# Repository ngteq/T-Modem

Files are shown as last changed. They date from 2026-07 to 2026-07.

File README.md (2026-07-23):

# T-Modem > USB-5V|12-Volt Terminal-Modem Reference
**Non-Profit for the Radio-World and easy to deploy/repair is parted by AI-Services**<br>
<br><br>
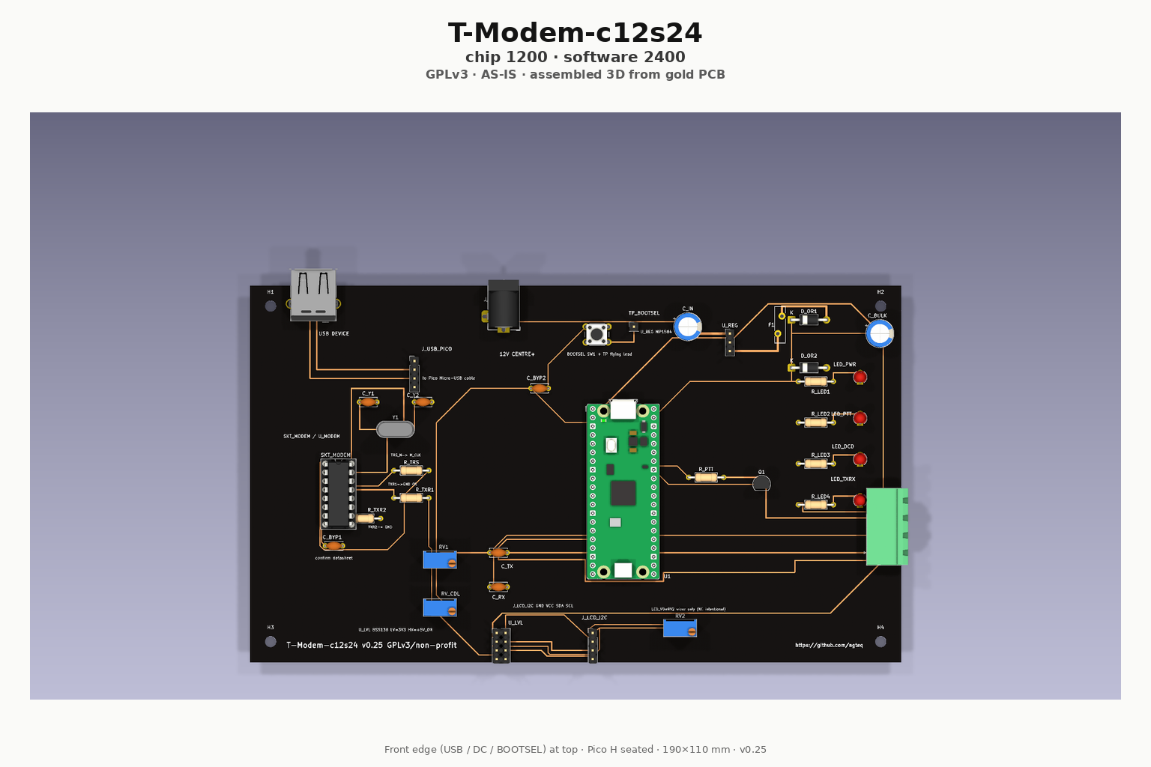
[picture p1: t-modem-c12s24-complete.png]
T-Modem-c12s24 complete assembled board (KiCad 3D, Pico seated)


<br>

> **No firmware / no host software yet** — trees under `firmware/` and `software/` are placeholders only.  
> **Build a working hardware prototype first** (rails, assembly, bench checks).
> KiCad PCB is for **learning-by-doing** and small-run fab — run **DRC** and fix reported issues before ordering boards.  

**T-Modem** = **Terminal-Modem** — a real packet-radio modem board (registers + firmware) for host stacks such as MAX25-Stack.

**PHY mark:** **T-Modem-c12s24** — **c12** = chip **1200** (TCM3105-class AFSK) · **s24** = software **2400** (Pico firmware DSP later). One board; **no** second 2400 modem IC.

**Version:** **0.25** — hardware-only standard reference (**baseline** while building toward **v1.0**; software after the build) · [docs/HARDWARE-BASELINE.md](docs/HARDWARE-BASELINE.md)  
**License:** [GNU GPLv3](LICENSE)  
**Project intent:** non-profit / non-commercial community hardware project under GPLv3 (no separate legal entity claimed here).

**AS-IS — no support, no warranty:** This project and all materials are provided **as-is**. There is **no support** and **no warranty** of any kind. GPLv3 already disclaims warranty; this is also **project policy**.

**Scope:** T-Modem is a **standard reference only**. Custom product lines, per-customer variants, or commercial SKUs beyond that reference are **not** T-Modem — they are separate projects.

**Status/State:** The **v0.25** hardware design is **not** being redesigned. Develop it **as-is** to **v1.0** by **building** the board; **firmware / software come after** that. Change HW only if the build proves a blocking error.

Product docs and repo practice follow the operator publication standard (KISS, technical-right only, GPLv3 non-profit). This repository holds the complete product (hardware, firmware, shipped docs).

**Git branch:** you are on **`c12s24`** (active product tree). GitHub **`main`** is an index only — see [BRANCHES.md](BRANCHES.md).

---

## v0.25 release (this tag)

| Ships | Does not ship |
|---|---|
| BOM with preferred commodity candidates + longevity notes | Firmware / host software |
| Fabricable netlist + KiCad project (190×110 mm TH PCB) | Fab-verified Gerbers without DRC pass |
| PCB outline + placement + assembly notes | Invented radio mic pinouts |
| Power · USB-A · green LCD · Pico UF2 · **TCM3105-class AFSK IF**
| **Hobby-friendly soldering** (sockets + through-hole) | Reflow / fine-pitch SMD as the default path |

See [docs/RELEASE-v0.25.md](docs/RELEASE-v0.25.md) · [docs/v0.25-VERIFICATION.md](docs/v0.25-VERIFICATION.md) · [docs/BOM.md](docs/BOM.md) · [docs/SCHEMATIC.md](docs/SCHEMATIC.md) · [docs/PCB-ASSEMBLY.md](docs/PCB-ASSEMBLY.md) · [hardware/](hardware/).

**Firmware / software:** placeholders only — [firmware/README.md](firmware/README.md) · [software/README.md](software/README.md).

---

## Hobby-friendly soldering

v0.25 is aimed at **hand soldering for anyone who can solder reasonably well** — not only professional reflow lines. Goal: **best value for money**, socketed, replaceable parts.

| Practice | Intent |
|---|---|
| **DIP / module sockets** | Modem IC in a **16-pin DIP socket**; Pico and LCD on **2.54 mm female sockets** |
| **Through-hole first** | Resistors, diodes, LEDs, trimmers, USB-A, barrel jack, screw terminals — **TH** (cheap commodity packs) |
| **Pre-made cheap modules** | Pico (~few €), green 16×2 LCD module, MP1584-class buck module — plug in, no fine-pitch MCU soldering |
| **I²C LCD level shift** | 5 V LCD1602 I²C backpack ↔ Pico 3.3 V: BSS138-class 4-ch module (**LV=3.3 V** · **HV=5 V** · GND common) — see [docs/BOM.md](docs/BOM.md) `U_LVL` |
| **Not required** | Stencil reflow, QFN/BGA, expensive milled sockets, or SOIC as the only modem package |

Assembly and cheap-part notes: [docs/PCB-ASSEMBLY.md](docs/PCB-ASSEMBLY.md) · [docs/BOM.md](docs/BOM.md) · [docs/ORDERING-BUDGET.md](docs/ORDERING-BUDGET.md).

---

## Role

| This repo | Elsewhere |
|---|---|
| Complete T-Modem **standard reference**: hardware, (future) firmware, BOM/PCB, shipped docs | MAX25-Stack: **thin plugin only** later (discover / talk; host keeps AX.25 / KISS) |
| Board owns modem PHY + register file + thin KISS bridge (when FW exists)

**Settled scope**

| Item | Fact |
|---|---|
| Form | Rectangle **190 × 110 mm** (v0.25 outline; §0.26 larger OK) |
| Modulation | AFSK **1200** (TCM3105-class) + **2400** (MCU DSP, FW later) |
| Host link | USB 2.0 **Type A receptacle** (toward PC); no active hub required |
| Power | **USB-only OK**; barrel **12 V** + buck **optional** (on reference); USB OR; optional active hub / **5 V** into USB/OR rail |
| Display | HD44780-class **16×2** character LCD, **green backlight** (preferred) |
| MCU | **Raspberry Pi Pico** (RP2040), preferably **Pico H** on socketed headers — ROM **UF2** field flash |
| Modem IC | **TCM3105**-class Bell-202 in **DIP + socket**
| Assembly | **Hobby-friendly:** sockets + through-hole; see section above |
| Field flash | Via the **USB Type-A** port to the PC (when FW exists) |
| Layer split | Host owns AX.25; board = modem + thin KISS |
| Radio equipment | Screw-terminal AF/PTT labels only — **no** invented mic pinouts |

---

## Build

| Step | v0.25 status |
|---|---|
| Schematic / netlist | **Documented** — [docs/SCHEMATIC.md](docs/SCHEMATIC.md) |
| KiCad project | **Present** — [hardware/kicad/t-modem/](hardware/kicad/t-modem/) (KiCad ≥8; docs images via `scripts/render_docs_images.py`) |
| PCB outline / placement | **Documented** — [docs/PCB-ASSEMBLY.md](docs/PCB-ASSEMBLY.md) · [docs/PCB-LAYOUT.md](docs/PCB-LAYOUT.md) |
| BOM | **Candidates** — [docs/BOM.md](docs/BOM.md) · [hardware/bom/BOM.csv](hardware/bom/BOM.csv) |
| Verification | [docs/v0.25-VERIFICATION.md](docs/v0.25-VERIFICATION.md) |
| Firmware tree | **Placeholder only** |
| Fab | **DRC clean** → export Gerbers — see [hardware/fab/README.md](hardware/fab/README.md). Personal small-run OK — **AS-IS** |

---

## Operate

| Topic | Status |
|---|---|
| Host attach (USB CDC/ACM) | **TBD** until firmware |
| Register map / KISS | **TBD** — see [docs/OVERVIEW.md](docs/OVERVIEW.md) |
| Radio cable / pinout per model | **TBD** — expand from verified notes only |
| RX before live TX | Operator practice when RF path exists |

Site-private secrets belong in `./local/` (gitignored) — never commit passwords or host inventories.

---

## Documentation

| Doc | Content |
|-----|---|
| [docs/README.md](docs/README.md) | Doc index |
| [docs/RELEASE-v0.25.md](docs/RELEASE-v0.25.md) | v0.25 hardware-only release note |
| [docs/v0.25-VERIFICATION.md](docs/v0.25-VERIFICATION.md) | Self-audit checklist |
| [docs/BOM.md](docs/BOM.md) | Bill of materials (candidates + sockets / TH hobby path) |
| [docs/ORDERING-BUDGET.md](docs/ORDERING-BUDGET.md) | Budget buy list — cheap, socketed, hand-solder |
| [docs/SCHEMATIC.md](docs/SCHEMATIC.md) | Fabricable netlist + block diagram |
| [docs/PCB-ASSEMBLY.md](docs/PCB-ASSEMBLY.md) | Outline, placement, hobby-friendly assembly |
| [docs/OVERVIEW.md](docs/OVERVIEW.md) | Settled product facts |
| [docs/HARDWARE-INTENT.md](docs/HARDWARE-INTENT.md) | Form, interfaces, radio intent |

Uncertain items are marked **TBD**. Do not treat TBD as verified capability.

---

## License and project intent

Copyright and distribution terms: **GNU General Public License v3** — see [LICENSE](LICENSE).

This is a **non-profit** open hardware / firmware project: share and change under GPLv3; not a commercial product pitch.

**AS-IS:** provided without support and without warranty of any kind (see notice at top of this README and GPLv3 §§15–16).

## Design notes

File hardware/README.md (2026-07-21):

# Hardware — T-Modem v0.25

**AS-IS** · **standard reference only** · GPLv3

| Path | Content |
|---|---|
| [bom/BOM.csv](bom/BOM.csv) | Machine-readable BOM |
| [kicad/t-modem/](kicad/t-modem/) | KiCad ≥8 / 10 project (190 × 110 mm) |
| [mechanical/outline-190x110.md](mechanical/outline-190x110.md) | Board outline |
| [fab/](fab/) | Gerber export notes + sample |

Human docs: [`../docs/BOM.md`](../docs/BOM.md) · [`../docs/SCHEMATIC.md`](../docs/SCHEMATIC.md) · [`../docs/PCB-ASSEMBLY.md`](../docs/PCB-ASSEMBLY.md) · [`../docs/RELEASE-v0.25.md`](../docs/RELEASE-v0.25.md) · [`../docs/HARDWARE-BASELINE.md`](../docs/HARDWARE-BASELINE.md).

**Not claimed:** production-verified Gerbers without DRC. Clear DRC before fab order.

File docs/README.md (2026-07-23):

# T-Modem documentation

English shipped docs only. Facts here must be settled; otherwise **TBD**.

Glossary of uncommon technical terms (repo **`main`** only): [`../docs/TERMS.md` on `main`](https://github.com/ngteq/T-Modem/blob/main/docs/TERMS.md) — not duplicated on this branch.

| Document | Role |
|---|---|
| [RELEASE-v0.25.md](RELEASE-v0.25.md) | **v0.25** hardware-only release |
| [HARDWARE-BASELINE.md](HARDWARE-BASELINE.md) | Settled HW → build to v1.0; software after |
| [HARDWARE-FREEZE.md](HARDWARE-FREEZE.md) | Redirect → baseline (old name) |
| [v0.25-VERIFICATION.md](v0.25-VERIFICATION.md) | Self-audit PASS/FAIL/TBD |
| [BOM.md](BOM.md) | Bill of materials (candidate MPNs, sockets / TH) |
| [ORDERING-BUDGET.md](ORDERING-BUDGET.md) | Cheap hobby buy list — best value, socketed |
| [SCHEMATIC.md](SCHEMATIC.md) | Fabricable netlist + power rationale |
| [PCB-ASSEMBLY.md](PCB-ASSEMBLY.md) | PCB outline + hobby assembly |
| [PCB-LAYOUT.md](PCB-LAYOUT.md) | Safe · stable · performant · KISS; prefer larger |
| [images/explode/](images/explode/) | KiCad-based explode teaching set (10 PNGs) |
| [OVERVIEW.md](OVERVIEW.md) | Product identity, layer split |
| [HARDWARE-INTENT.md](HARDWARE-INTENT.md) | Form factor, USB/PSU, radio intent |

Branch model: [`../BRANCHES.md`](../BRANCHES.md) · Hardware tree: [`../hardware/`](../hardware/) · Firmware placeholder: [`../firmware/`](../firmware/) · Software placeholder: [`../software/`](../software/).

Governance: KISS · technical/legal only · GPLv3 non-profit · **AS-IS**.

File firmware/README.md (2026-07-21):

# Firmware — placeholder (v0.25)

**Status:** **no firmware** in this release.

v0.25 is a **hardware-only** standard reference (BOM, schematic netlist, PCB outline/placement). Application firmware (register file, KISS, AFSK 1200/2400, LCD UI, UF2 image) is **out of scope** for tag `v0.25`.

| Later (not v0.25) | Notes |
|---|---|
| UF2 / USB CDC | RP2040 ROM UF2 already provides field flash path once an image exists |
| KISS + registers | Board owns PHY; host owns AX.25 |
| AFSK | TCM3105 path for 1200; 2400 via MCU DSP |

**AS-IS:** no support, no warranty.

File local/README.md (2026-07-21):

# Local config (gitignored except this file)

Copy examples into this directory for site-private secrets and paths.
Never commit live passwords, hostnames, or UART inventories.

Generate secrets with the operator vault tooling when scaffolding.

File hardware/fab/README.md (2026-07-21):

# Fabrication export — T-Modem v0.25

**AS-IS** · GPLv3 · standard reference only

Gerbers in this tree are produced with `kicad-cli` (KiCad 10). Re-export after any PCB edit.

## CLI (headless)

```bash
export HOME=/tmp/kicad-home   # or a writable KiCad config home
mkdir -p "$HOME/.config/kicad/10.0"

PCB=hardware/kicad/t-modem/t-modem.kicad_pcb
OUT=hardware/fab/gerbers
mkdir -p "$OUT"

kicad-cli pcb drc --refill-zones --save-board --format report \
  --output hardware/fab/drc-report.txt --units mm "$PCB"

kicad-cli pcb export gerbers -o "$OUT/" \
  --layers "F.Cu,B.Cu,F.SilkS,B.SilkS,F.Mask,B.Mask,Edge.Cuts" "$PCB"

kicad-cli pcb export drill -o "$OUT/" "$PCB"
```

## GUI

File → Fabrication Outputs → Gerbers (+ Drill Files). Match layer set above. Zip `gerbers/` for the fab house.

## Board

| Item | Value |
|---|---|
| Size | **190 × 110 mm** (grown from 160×100 for courtyard/spacing §0.26) |
| Thickness | 1.6 mm |
| Layers | 2 |
| Finish | operator choice (HASL/ENIG) |

Review DRC before ordering. **2026-07-21:** auto-router + stitches — **6 unconnected** (mostly GND pour islands), **4 shorts** (B.Cu 3V3/I2C, AF_RX vs I2C, LED_TXRX_N vs PTT_OC). **Route remaining in pcbnew** (~15 min) before fab.

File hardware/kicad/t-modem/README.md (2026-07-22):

# KiCad project — T-Modem v0.25

Open **`t-modem.kicad_pro`** in **KiCad ≥ 8** (tested with **KiCad 10**).

| File | Role |
|---|---|
| `t-modem.kicad_pro` | Project |
| `t-modem.kicad_sch` | Schematic + embedded symbols |
| `t-modem.kicad_sym` | Custom TCM3105 + Pico subset |
| `t-modem.kicad_pcb` | **190×110 mm** board — copper DRC short/unconn/cross **0/0/0** (prototype-ready) |
| `sym-lib-table` | Points at `t-modem.kicad_sym` |

## Operator steps

1. Open **`t-modem.kicad_pro`** → run **DRC**.  
2. Silk cosmetic warnings may remain (`silk_over_copper` / overlap) — OK for prototype.  
3. Export Gerbers + drill — see [`../../fab/README.md`](../../fab/README.md).

**Authoritative electrical design:** [`../../../docs/SCHEMATIC.md`](../../../docs/SCHEMATIC.md)  
**Assembly:** [`../../../docs/PCB-ASSEMBLY.md`](../../../docs/PCB-ASSEMBLY.md)

**AS-IS:** no support, no warranty · GPLv3 · standard reference only · **not** BayCom/SER12.

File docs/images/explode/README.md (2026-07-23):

# Exploded assembly drawings (from KiCad PCB)

Teaching sequence for builders — **2D top view** exported from gold
`hardware/kicad/t-modem/t-modem.kicad_pcb` (not mechanical CAD / not 3D).

Front edge (USB / DC / BOOTSEL) is at the **bottom** of each image.

Regenerate explode only: `python3 hardware/kicad/t-modem/scripts/render_docs_images.py --explode`  
Repo-root complete (assembled 3D): default `python3 …/render_docs_images.py` (does not rewrite this set).

| # | File | Topic |
|---|---|---|
| 1 | [t-modem-explode-01-board-outline.png](t-modem-explode-01-board-outline.png) | Board outline · M3 |
| 2 | [t-modem-explode-02-pico.png](t-modem-explode-02-pico.png) | Raspberry Pi Pico |
| 3 | [t-modem-explode-03-modem-socket.png](t-modem-explode-03-modem-socket.png) | DIP-16 socket · TCM3105 |
| 4 | [t-modem-explode-04-crystal.png](t-modem-explode-04-crystal.png) | Crystal · load caps |
| 5 | [t-modem-explode-05-radio-af.png](t-modem-explode-05-radio-af.png) | J_AF radio AF/PTT |
| 6 | [t-modem-explode-06-lcd-i2c.png](t-modem-explode-06-lcd-i2c.png) | LCD I²C · level shift |
| 7 | [t-modem-explode-07-usb.png](t-modem-explode-07-usb.png) | USB Path B |
| 8 | [t-modem-explode-08-straps-leds.png](t-modem-explode-08-straps-leds.png) | Straps · LEDs · trimmers |
| 9 | [t-modem-explode-09-power-dc.png](t-modem-explode-09-power-dc.png) | 12 V · buck · OR-ing |
| 10 | [t-modem-explode-10-complete-stack.png](t-modem-explode-10-complete-stack.png) | Complete stack |

PNG · 1536×1024 · branch **`c12s24`** · companion (assembled 3D with Pico): repo-root [`t-modem-c12s24-complete.png`](../../../t-modem-c12s24-complete.png).

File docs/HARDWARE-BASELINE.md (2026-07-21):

# Hardware baseline — path to v1.0

**Status:** settled 2026-07-20 · wording update 2026-07-21  
**Baseline:** git tag **`v0.25`**

| Phase | Fact |
|---|---|
| **Hardware** | Design **settled** as v0.25 (BOM/sockets/TH, netlist, outline **190 × 110 mm**). No redesign for preference. |
| **Operator** | **Build** the reference → prove rails / assembly → hardware **v1.0** when the built unit matches. |
| **Software** | Firmware, host tools, MAX25 plugin — **after** the hardware build path. Placeholders until then. |
| **Allowed HW edits** | Only **blocking** fab/assembly errors proven on the bench; outline/spacing growth OK ([PCB-LAYOUT.md](PCB-LAYOUT.md)). |
| **PCB finish** | Complete place/route/Gerbers; prefer **larger** over fiddly — [PCB-LAYOUT.md](PCB-LAYOUT.md) |
| **Power** | USB-only is enough; 12 V barrel + buck **optional** but on the reference — [SCHEMATIC.md](SCHEMATIC.md) |

**AS-IS** · **standard reference only**. PCB policy: [PCB-LAYOUT.md](PCB-LAYOUT.md).

Former filename `HARDWARE-FREEZE.md` redirects here (same policy, clearer wording).

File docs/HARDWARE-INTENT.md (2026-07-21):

# Hardware intent

**Status:** active — aligned with **v0.25** hardware reference  
**AS-IS:** no support, no warranty · **standard reference only**

---

## Form factor

| Item | Intent / v0.25 |
|---|---|
| Shape | Classic **rectangle** |
| Outline | **190 × 110 mm** — [PCB-ASSEMBLY.md](PCB-ASSEMBLY.md) |
| PCB | 2-layer FR4; TH / 0805 |
| Front/rear | USB Type A · barrel 12 V · AF/PTT screw · 16×2 green LCD · LEDs |
| Fab | Easy fab; personal small-run OK |

---

## Electrical / host

| Item | Intent / v0.25 |
|---|---|
| USB | Type-A **receptacle**, device role |
| Power | **USB-only OK** (`D_OR2` → `+5V_OR`); barrel **12 V** + buck **optional** (on reference, not required); optional active hub or regulated **5 V** into USB/OR path — [SCHEMATIC.md](SCHEMATIC.md) Power rationale |
| MCU | Raspberry Pi Pico (RP2040) |
| Field flash | UF2 via USB (BOOTSEL) |
| Host protocol | Thin KISS + registers (**FW later**) |
| Modulation | AFSK 1200 + 2400 (**FW later**) |
| Display | HD44780 16×2 green preferred |

See [BOM.md](BOM.md) · [SCHEMATIC.md](SCHEMATIC.md).

---

## Radio-equipment support

| Do | Don't |
|----|---|
| Function labels on screw terminal | Fake “supported radios” list |
| Mark pinouts TBD until verified | Invent connector pinouts |
| Prove RX before live TX when RF exists | Treat untested cables as features |

---

## Explicitly not this product

| Out | Reason |
|-----|---|
| BayCom/based SER12 | Different product class |
| Albrecht PC-COM / soft-TNC UART clone | Not board modem with registers |
| Framing as BayCom replacement | Separate workstreams |

---

## Sources

| Claim | Rights-granting source | Local copy |
|---|---|---|
| GPLv3 | https://www.gnu.org/licenses/gpl-3.0.html | `../LICENSE` |
| Pico | https://datasheets.raspberrypi.com/pico/pico-datasheet.pdf | — |

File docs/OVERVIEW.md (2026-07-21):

# T-Modem overview

**Status:** active — settled facts  
**Version:** **0.25** (hardware-only milestone)  
**Name:** **T-Modem** = **Terminal-Modem**  
**PHY mark:** **T-Modem-c12s24** — chip **1200** + software **2400**  
**License:** GNU GPLv3 (repo root `LICENSE`)  
**Project intent:** non-profit / non-commercial community hardware under GPLv3

**AS-IS:** provided **as-is** — **no support**, **no warranty** of any kind.

**Scope:** **standard reference only** — derivatives / custom lines = separate projects, not T-Modem.

| PHY | Owner |
|-----|---|
| **1200** AFSK Bell-202 | **Chip** — TCM3105-class (`U_MODEM`) |
| **2400** AFSK | **Software** — Pico RP2040 firmware (**after** HW prototype) |

---

## What it is

T-Modem is a **real board modem** with **registers and firmware** on the device (**firmware not in v0.25**). The host (for example MAX25-Stack) owns AX.25 and higher services. The board provides AFSK PHY, a modem register file, and a thin KISS bridge — a transparent half-TNC / modem+TNC mix.

| Settled | Fact |
|---|---|
| Product home | This repository = **standard reference** |
| v0.25 | Hardware package (BOM / schematic intent / PCB notes / KiCad skeleton) |
| Beyond reference | Custom / commercial SKU variants → **separate projects** |
| MAX25 role | **Thin plugin only** later |
| Modulation | **c12s24:** AFSK **1200** (chip) + **2400** (Pico FW later) — one unit |
| Host interface | USB 2.0 **Type A receptacle**; no active hub required |
| Power | **USB-only OK**; optional barrel **12 V** + buck on reference; optional active hub / **5 V** into USB/OR — [SCHEMATIC.md](SCHEMATIC.md) |
| Display | 16×2 HD44780 **green** preferred |
| MCU | Raspberry Pi Pico (RP2040), UF2 USB flash — host + **s24** DSP later |
| Form | Rectangle **190 × 110 mm** (v0.25) |
| Not this product | BayCom/based · SER12 · PC-COM soft-TNC · host UART bitbang modem |

---

## Layer split

| Layer | Owner |
|---|---|
| AX.25, digipeat, BBX/UI / services | Host (e.g. MAX25 / HyBBX) |
| KISS framing / thin cmds | Board firmware (**later**) |
| Modem registers | Board firmware (**later**) |
| AFSK 1200 / 2400 PHY | On-board (**FW later**) |
| AF TX/RX + PTT | Analog IF on board (**HW in v0.25**) |
| USB 2.0 device | Board (**HW in v0.25**; CDC profile **TBD**) |

---

## Radio equipment

**Operator lock:** radio equipment **must be supported** and remain **expandable**.

| Settled intent | Not claimed |
|---|---|
| Screw terminals: AF_TX, AF_RX, PTT, GND | Named radio model list |
| Expand after verification | Invented mic pinouts |

---

## TBD (explicit)

| Item | Status |
|---|---|
| Exact connector MPNs at order | TBD — pick in-stock DigiKey/Mouser |
| Register map bytes | TBD (FW) |
| USB VID/PID / CDC details | TBD (FW) |
| Gerbers / DRC | TBD — clear DRC before fab order |
| Per-radio cable pinouts | TBD |

---

## Sources

| Claim | Rights-granting source | Local copy |
|---|---|---|
| License GPLv3 | https://www.gnu.org/licenses/gpl-3.0.html | `LICENSE` |
| Pico / RP2040 | https://datasheets.raspberrypi.com/pico/pico-datasheet.pdf | — |

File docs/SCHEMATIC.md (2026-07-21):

# Schematic / netlist — v0.25

**Status:** complete **electrical + PCB** for first fab — Gerbers generatable from KiCad project  
**KiCad:** [`../hardware/kicad/t-modem/`](../hardware/kicad/t-modem/) · fab [`../hardware/fab/`](../hardware/fab/) (open in KiCad ≥8 / 10)  
**Board:** **190 × 110 mm** · Path B USB + I²C LCD **settled** for v0.25 complete PCB  
**AS-IS:** no support, no warranty · **standard reference only**

This document is the **authoritative netlist** for v0.25. Gerbers are exportable; operator must clear remaining DRC (signal finish) before fab order. No measured radio performance claimed.

---

## Block diagram

```text
  12 V barrel ──► buck/LDO ──► +5V ──┬── Pico VSYS (+ Schottky OR with VBUS)
  USB-A (device) ── D+/D−/GND/VBUS ──┤── Pico USB · UF2 BOOTSEL
                                    ├── TCM3105 VDD (5 V)
                                    └── LCD backlight / logic (5 V or 3.3 V module)

  J_AF AF_RX ── AC ──► TCM3105 RXA ── RXD/CDT ──► Pico GPIO
  Pico GPIO TXD ──► TCM3105 TXD ── TXA ── pot ── AC ──► J_AF AF_TX
  Pico GPIO PTT ──► NPN OC ──► J_AF PTT
  Pico ── parallel ──► 16×2 green LCD
  Pico I²C (3.3 V) ── U_LVL (LV/HV) ──► 5 V I²C backpack ──► LCD1602
```

**Not BayCom/SER12:** no DTR bitclock, no RTS-as-PHY, no TXD charge-pump modem. Host USB is CDC/KISS later; air path is TCM3105-class FSK + MCU.

---

## Rails

| Net | Source | Notes |
|-----|---|---|
| `VIN_12` | J_DC tip (centre +) | 9–14 V class; silk **12 V CENTRE +** — **optional** path (see Power rationale) |
| `GND` | J_DC sleeve · USB GND · analog GND star near U_MODEM | Single ground plane preferred |
| `+5V` | U_REG out | After polyfuse F1 — only when barrel+buck fitted |
| `VBUS` | J_USB VBUS | Through D_OR2 into `+5V_OR`; USB-only supply uses this leg |
| `+5V_OR` | cathode junction D_OR1 (from U_REG) + D_OR2 (from VBUS) | Feeds Pico `VSYS`, TCM3105 `VDD`, LCD — **either** OR leg sufficient |
| `3V3` | Pico on-board 3.3 V | GPIO logic; with 5 V LCD I²C backpack use **U_LVL** — **LV=`3V3`** · **HV=`+5V_OR`** · **GND** common (BSS138-class; not for TFT) |

---

## Connectors

### J_DC — barrel 5.5×2.1 mm centre-positive

| Pin | Net |
|-----|-----|
| Tip | `VIN_12` |
| Sleeve | `GND` |

### J_USB — USB Type-A receptacle (device toward PC)

| Pin | Net | Pico (U1) |
|-----|-----|---|
| VBUS | `VBUS` | — (OR diodes only) |
| D− | `USB_DM` | Pico pin **USB_DM** (board USB pads / GP) |
| D+ | `USB_DP` | Pico pin **USB_DP** |
| GND | `GND` | GND |
| Shield | `GND` | via 0 Ω or direct |

**Path B (settled for v0.25 complete PCB):** Type-A receptacle on board. VBUS → Schottky OR (`D_OR2`) into `+5V_OR`. D+/D−/GND (+ VBUS) also to 4-pin header `J_USB_PICO` — silk **to Pico Micro-USB cable**. Short cable from header to Pico Micro-USB for data + UF2.

PC sees one USB device on the Type-A receptacle; UF2 works when BOOTSEL held at plug-in (board SW1 → `TP_BOOTSEL` flying lead to Pico BOOTSEL pad if needed).

### J_AF — 4-pin screw 5.08 mm (function labels only)

| Pin silk | Net | Role |
|---|-----|---|
| `AF_TX` | `AF_TX` | Audio to radio mic / TX AF |
| `AF_RX` | `AF_RX` | Audio from radio speaker / RX AF |
| `PTT` | `PTT_OC` | Open-collector to radio PTT |
| `GND` | `GND` | Common |

No mic pinout map claimed.

---

## Power rationale

| Path | Role | Required to run? |
|---|---|---|
| **USB → `D_OR2` → `+5V_OR`** | Full board supply from VBUS | **No** barrel needed — **USB-only is a complete alternative** |
| **`J_DC` + `U_REG` → `D_OR1` → `+5V_OR`** | 12 V barrel + buck → 5 V | **Not required** for operation; **planned and on the reference** for radio/station wall-warts and future mods that want PSU headroom |
| USB host / **active hub** / stronger USB 5 V | Same `VBUS` → `D_OR2` leg | Hub **optional** (budget ≪ host port limit; use hub when preferred) |
| Optional **5 V** regulated PSU | Into the **USB / OR 5 V domain** | **Planned option** — feed regulated 5 V at the `VBUS` node (before `D_OR2`) or an auxiliary wire to the `+5V_OR` side of the OR; **no second barrel class** on the v0.25 BOM (only `J_DC` 12 V + `J_USB`) |

**KISS:** one OR rail (`+5V_OR`). Either diode leg can power the board. Do **not** put 12 V on Pico / modem / LCD rails.

---

## Power path

| Ref | Connection |
|-----|---|
| J_DC tip | `VIN_12` (optional inlet) |
| C_IN 100 µF/25 V | `VIN_12`–`GND` |
| U_REG IN | `VIN_12`; U_REG GND → `GND`; U_REG OUT → `+5V_REG` |
| F1 PTC | `+5V_REG` → `+5V` |
| D_OR1 Schottky | anode `+5V` → cathode `+5V_OR` |
| D_OR2 Schottky | anode `VBUS` → cathode `+5V_OR` |
| C_BULK 100 µF | `+5V_OR`–`GND` |
| C_BYP×N 100 nF | each IC VDD–GND |

Pico: `VSYS` ← `+5V_OR`; `GND` ← `GND`. Do **not** feed 12 V into Pico. USB-only: leave `J_DC` / `U_REG` unpowered; `D_OR2` alone supplies `+5V_OR`.

---

## MCU — U1 Raspberry Pi Pico (RP2040)

| Pico net / pin (board edge) | Net | Role |
|---|-----|---|
| VSYS | `+5V_OR` | Power |
| GND | `GND` | Ground |
| 3V3 | `3V3` | Sense / LCD if 3.3 V module |
| BOOTSEL | SW1 → `GND` | UF2 entry |
| GP0 | `I2C_SDA_3V3` | → U_LVL LV → LCD backpack SDA |
| GP1 | `I2C_SCL_3V3` | → U_LVL LV → LCD backpack SCL |
| GP6 | `MODEM_TXD` | → TCM3105 TXD |
| GP7 | `MODEM_RXD` | ← TCM3105 RXD |
| GP8 | `MODEM_CDT` | ← TCM3105 CDT (DCD LED / FW) |
| GP9 | `PTT_DRV` | → R_PTT → Q1 base |
| GP10 | `LED_PTT` | |
| GP11 | `LED_DCD` | |
| GP12 | `LED_TXRX` | |
| VSYS | `+5V_OR` | Power |
| BOOTSEL | SW1 / TP_BOOTSEL | UF2 entry |
| USB (Path B) | via `J_USB_PICO` cable | Type-A → Pico Micro-USB |

LED_PWR: hardwire anode to `+5V_OR` via R_LED, cathode to GND (always-on when powered).

---

## Modem IC — U_MODEM TCM3105 (16-pin DIP/SO class)

Bell 202 **1200** AFSK PHY. **2400** = firmware DSP on Pico (later) — not TCM3105 headline rate.

| Pin | Name | Net / strap |
|-----|---|---|
| 1 | VDD | `+5V_OR` |
| 2 | CLK | NC or test pad |
| 3 | CDT | `MODEM_CDT` |
| 4 | RXA | `RXA` (from AF_RX path) |
| 5 | TRS | `GND` (Bell 202 class — confirm per datasheet mode table at fab) |
| 6 | NC | NC |
| 7 | RXB | RV_RXB wiper (bias pot) or datasheet recommended R network |
| 8 | RXD | `MODEM_RXD` |
| 9 | VSS | `GND` |
| 10 | CDL | RV_CDL / R network (carrier detect level) |
| 11 | TXA | `TXA` |
| 12 | TXR2 | `R_TXR2` 0 Ω → `+5V_OR` default (Bell 202 1200) — silk **confirm datasheet** |
| 13 | TXR1 | `R_TXR1` 0 Ω → `GND` default (Bell 202 1200) — silk **confirm datasheet** |
| 14 | TXD | `MODEM_TXD` |
| 15 | OSC1 | Y1 4.4336 MHz crystal (or datasheet Xtal) |
| 16 | OSC2 | Y1 other leg + load caps |

**Longevity:** TCM3105 is a **legacy** TI/MX-COM-era part — often **NOS / broker**. Prefer in-stock DIP/SO when ordering; if unavailable, substitute **MX614**-class Bell-202 modem IC (same role nets) or document MCU soft-AFSK only — mark substitute in BOM.

Sources: TCM3105 datasheet (TI historical) — e.g. https://www.qsl.net/o/on7pc/datasheet/ic/TCM3105.pdf

### Analog IF around U_MODEM

| From | Via | To |
|---|-----|-----|
| `AF_RX` | C_RX 100 nF · optional R pad | `RXA` |
| `TXA` | RV1 10 kΩ (TX level) · C_TX 100 nF · R_PAD | `AF_TX` |
| Clamp | D_PROT 1N4148 to rails | `AF_RX` / `AF_TX` as needed |

---

## PTT

| From | Via | To |
|---|-----|-----|
| `PTT_DRV` | R_PTT 4.7 kΩ | Q1 base (2N2222A) |
| Q1 emitter | — | `GND` |
| Q1 collector | — | `PTT_OC` → J_AF `PTT` |
| Optional | LED_PTT driven from `PTT_DRV` | |

---

## Display — DSP1 16×2 HD44780 green

| LCD pin (typical) | Net |
|---|-----|
| VSS | `GND` |
| VDD | `+5V_OR` (or `3V3` if module rated) |
| V0 | RV2 contrast wiper |
| RS, E, D4–D7 | as MCU table (or backpack I²C on GP0/GP1 via **U_LVL**) |
| A / K backlight | `+5V_OR` via R_BL · `GND` — **green** LED backlight |

### U_LVL — I²C level shifter (when using 5 V backpack)

| Side | Net | Note |
|---|-----|---|
| LV | `3V3` | Pico side |
| HV | `+5V_OR` | LCD1602 green I²C backpack (5 V) |
| GND | `GND` | Common |
| SDA/SCL | GP0/GP1 ↔ backpack | Bidirectional BSS138-class module |

**Not** for TFT. Parallel 4-bit LCD on 5 V with series resistors or 3.3 V–tolerant module may omit U_LVL.

TFT alt: not default — see [HARDWARE-INTENT.md](HARDWARE-INTENT.md) (optional; longevity weaker than character LCD).

---

## Fabrication contract

| Deliverable | v0.25 |
|---|---|
| Netlist + BOM + **190×110** PCB (KiCad) | **Yes** — complete TH reference |
| USB Path B + I²C LCD | **Settled** |
| Gerbers generatable (`kicad-cli` / GUI) | **Yes** — see `hardware/fab/` |
| DRC zero / production-verified | **Not claimed** — finish signal tracks; clear DRC before order |
| Firmware | Placeholder — nets reserved |

---

## Sources

| Claim | Rights-granting source | Local copy |
|---|---|---|
| TCM3105 FSK modem (historical TI datasheet mirrors) | https://www.qsl.net/o/on7pc/datasheet/ic/TCM3105.pdf | — |
| RP2040 / Pico | https://datasheets.raspberrypi.com/rp2040/rp2040-datasheet.pdf · https://datasheets.raspberrypi.com/pico/pico-datasheet.pdf | — |
| HD44780U | https://cdn.sparkfun.com/assets/9/5/f/7/b/HD44780.pdf | — |
| GPLv3 | https://www.gnu.org/licenses/gpl-3.0.html | `../LICENSE` |

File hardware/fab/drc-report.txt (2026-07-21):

** Drc report for t-modem.kicad_pcb **
** Created on 2026-07-21T11:25:35 **
** Report includes: Errors, Warnings **

** Found 293 DRC violations **
[hole_clearance]: Loch-Freiraum-Verstoß (Einschränkungen aus Platinenkonfiguration zu Löchern Freiraum 0,2500 mm; tatsächlich 0,0000 mm)
    Rule: Einschränkungen aus Platinenkonfiguration zu Löchern; error
    @(186.0000 mm, 104.0000 mm): Leiterbahn [AF_RX] auf B.Cu, Länge 116.0000 mm
    @(184.0000 mm, 104.0000 mm): NPTH-Pad von H4
[hole_clearance]: Loch-Freiraum-Verstoß (Einschränkungen aus Platinenkonfiguration zu Löchern Freiraum 0,2500 mm; tatsächlich 0,2250 mm)
    Rule: Einschränkungen aus Platinenkonfiguration zu Löchern; error
    @(186.0000 mm, 72.9200 mm): Leiterbahn [AF_RX] auf B.Cu, Länge 31.0800 mm
    @(184.0000 mm, 104.0000 mm): NPTH-Pad von H4
[tracks_crossing]: Tracks crossing
    Local override; error
    @(72.0000 mm, 18.0000 mm): Leiterbahn [3V3] auf B.Cu, Länge 84.0000 mm
    @(102.5400 mm, 18.0000 mm): Leiterbahn [MODEM_CDT] auf B.Cu, Länge 78.0000 mm
[tracks_crossing]: Tracks crossing
    Local override; error
    @(138.0000 mm, 18.0000 mm): Leiterbahn [3V3] auf B.Cu, Länge 66.0000 mm
    @(102.5400 mm, 61.4000 mm): Leiterbahn [MODEM_CDT] auf B.Cu, Länge 43.4000 mm
[tracks_crossing]: Tracks crossing
    Local override; error
    @(24.5400 mm, 57.0800 mm): Leiterbahn [MODEM_CDT] auf B.Cu, Länge 2.5400 mm
    @(24.5400 mm, 18.0000 mm): Leiterbahn [MODEM_RXD] auf B.Cu, Länge 51.7800 mm
[tracks_crossing]: Tracks crossing
    Local override; error
    @(72.0000 mm, 18.0000 mm): Leiterbahn [3V3] auf B.Cu, Länge 84.0000 mm
    @(102.5400 mm, 18.0000 mm): Leiterbahn [MODEM_RXD] auf B.Cu, Länge 78.0000 mm
[tracks_crossing]: Tracks crossing
    Local override; error
    @(102.5400 mm, 58.8600 mm): Leiterbahn [MODEM_RXD] auf B.Cu, Länge 40.8600 mm
    @(102.5400 mm, 61.4000 mm): Leiterbahn [MODEM_CDT] auf B.Cu, Länge 43.4000 mm
[tracks_crossing]: Tracks crossing
    Local override; error
    @(100.0000 mm, 58.8600 mm): Leiterbahn [MODEM_RXD] auf B.Cu, Länge 2.5400 mm
    @(102.5400 mm, 61.4000 mm): Leiterbahn [MODEM_CDT] auf B.Cu, Länge 43.4000 mm
[tracks_crossing]: Tracks crossing
    Local override; error
    @(72.0000 mm, 18.0000 mm): Leiterbahn [3V3] auf B.Cu, Länge 84.0000 mm
    @(100.0000 mm, 56.3200 mm): Leiterbahn [MODEM_TXD] auf B.Cu, Länge 70.3800 mm
[tracks_crossing]: Tracks crossing
    Local override; error
    @(72.0000 mm, 18.0000 mm): Leiterbahn [3V3] auf B.Cu, Länge 84.0000 mm
    @(48.0000 mm, 22.0000 mm): Leiterbahn [VBUS] auf B.Cu, Länge 120.1600 mm
[tracks_crossing]: Tracks crossing
    Local override; error
    @(102.5400 mm, 18.0000 mm): Leiterbahn [MODEM_RXD] auf B.Cu, Länge 78.0000 mm
    @(48.0000 mm, 8.0000 mm): Leiterbahn [VBUS] auf B.Cu, Länge 14.0000 mm
[clearance]: Freiraum-Verstoß ( Freiraum 0,2000 mm; tatsächlich 0,0600 mm)
    Local override; error
    @(24.1300 mm, 58.4200 mm): Leiterbahn [CDL] auf B.Cu, Länge 1.2700 mm
    @(24.5400 mm, 18.0000 mm): Leiterbahn [MODEM_RXD] auf B.Cu, Länge 51.7800 mm
[clearance]: Freiraum-Verstoß ( Freiraum 0,2000 mm; tatsächlich 0,0600 mm)
    Local override; error
    @(24.1300 mm, 59.6900 mm): Leiterbahn [CDL] auf B.Cu, Länge 1.2700 mm
    @(24.5400 mm, 18.0000 mm): Leiterbahn [MODEM_RXD] auf B.Cu, Länge 51.7800 mm
[clearance]: Freiraum-Verstoß ( Freiraum 0,2000 mm; tatsächlich 0,0600 mm)
    Local override; error
    @(24.1300 mm, 60.9600 mm): Leiterbahn [CDL] auf B.Cu, Länge 1.2700 mm
    @(24.5400 mm, 18.0000 mm): Leiterbahn [MODEM_RXD] auf B.Cu, Länge 51.7800 mm
[clearance]: Freiraum-Verstoß ( Freiraum 0,2000 mm; tatsächlich 0,0600 mm)
    Local override; error
    @(24.1300 mm, 63.5000 mm): Leiterbahn [CDL] auf B.Cu, Länge 1.2700 mm
    @(24.5400 mm, 18.0000 mm): Leiterbahn [MODEM_RXD] auf B.Cu, Länge 51.7800 mm
[clearance]: Freiraum-Verstoß ( Freiraum 0,2000 mm; tatsächlich 0,0600 mm)
    Local override; error
    @(24.5400 mm, 18.0000 mm): Leiterbahn [MODEM_RXD] auf B.Cu, Länge 51.7800 mm
    @(24.1300 mm, 64.7700 mm): Leiterbahn [CDL] auf B.Cu, Länge 1.2700 mm
[clearance]: Freiraum-Verstoß ( Freiraum 0,2000 mm; tatsächlich 0,0600 mm)
    Local override; error
    @(24.5400 mm, 18.0000 mm): Leiterbahn [MODEM_RXD] auf B.Cu, Länge 51.7800 mm
    @(24.1300 mm, 66.0400 mm): Leiterbahn [CDL] auf B.Cu, Länge 1.2700 mm
[tracks_crossing]: Tracks crossing
    Local override; error
    @(25.4000 mm, 66.0400 mm): Leiterbahn [CDL] auf B.Cu, Länge 1.2700 mm
    @(24.5400 mm, 18.0000 mm): Leiterbahn [MODEM_RXD] auf B.Cu, Länge 51.7800 mm
[tracks_crossing]: Tracks crossing
    Local override; error
    @(24.5400 mm, 18.0000 mm): Leiterbahn [MODEM_RXD] auf B.Cu, Länge 51.7800 mm
    @(24.1300 mm, 67.3100 mm): Leiterbahn [CDL] auf B.Cu, Länge 1.2700 mm
[clearance]: Freiraum-Verstoß ( Freiraum 0,2000 mm; tatsächlich 0,0600 mm)
    Local override; error
    @(24.5400 mm, 18.0000 mm): Leiterbahn [MODEM_RXD] auf B.Cu, Länge 51.7800 mm
    @(24.1300 mm, 62.2300 mm): Leiterbahn [CDL] auf B.Cu, Länge 1.2700 mm
[clearance]: Freiraum-Verstoß ( Freiraum 0,2000 mm; tatsächlich 0,0600 mm)
    Local override; error
    @(22.8600 mm, 67.3100 mm): Leiterbahn [CDL] auf B.Cu, Länge 1.2700 mm
    @(24.5400 mm, 18.0000 mm): Leiterbahn [MODEM_RXD] auf B.Cu, Länge 51.7800 mm
[tracks_crossing]: Tracks crossing
    Local override; error
    @(72.0000 mm, 18.0000 mm): Leiterbahn [3V3] auf B.Cu, Länge 84.0000 mm
    @(16.0000 mm, 84.0000 mm): Leiterbahn [RXA] auf B.Cu, Länge 59.0000 mm
[hole_clearance]: Loch-Freiraum-Verstoß (Einschränkungen aus Platinenkonfiguration zu Löchern Freiraum 0,2500 mm; tatsächlich 0,0000 mm)
    Rule: Einschränkungen aus Platinenkonfiguration zu Löchern; error
    @(5.0800 mm, 102.8700 mm): Leiterbahn [I2C_SCL_3V3] auf B.Cu, Länge 1.2700 mm
    @(6.0000 mm, 104.0000 mm): NPTH-Pad von H3
[hole_clearance]: Loch-Freiraum-Verstoß (Einschränkungen aus Platinenkonfiguration zu Löchern Freiraum 0,2500 mm; tatsächlich 0,0000 mm)
    Rule: Einschränkungen aus Platinenkonfiguration zu Löchern; error
    @(6.3500 mm, 102.8700 mm): Leiterbahn [I2C_SCL_3V3] auf B.Cu, Länge 1.2700 mm
    @(6.0000 mm, 104.0000 mm): NPTH-Pad von H3
[hole_clearance]: Loch-Freiraum-Verstoß (Einschränkungen aus Platinenkonfiguration zu Löchern Freiraum 0,2500 mm; tatsächlich 0,0000 mm)
    Rule: Einschränkungen aus Platinenkonfiguration zu Löchern; error
    @(6.3500 mm, 101.6000 mm): Leiterbahn [I2C_SCL_3V3] auf B.Cu, Länge 1.2700 mm
    @(6.0000 mm, 104.0000 mm): NPTH-Pad von H3
[tracks_crossing]: Tracks crossing
    Local override; error
    @(25.4000 mm, 34.2900 mm): Leiterbahn [I2C_SCL_3V3] auf B.Cu, Länge 1.2700 mm
    @(24.5400 mm, 18.0000 mm): Leiterbahn [MODEM_RXD] auf B.Cu, Länge 51.7800 mm
[clearance]: Freiraum-Verstoß ( Freiraum 0,2000 mm; tatsächlich 0,0600 mm)
    Local override; error
    @(24.5400 mm, 18.0000 mm): Leiterbahn [MODEM_RXD] auf B.Cu, Länge 51.7800 mm
    @(24.1300 mm, 34.2900 mm): Leiterbahn [I2C_SCL_3V3] auf B.Cu, Länge 1.2700 mm
[tracks_crossing]: Tracks crossing
    Local override; error
    @(72.0000 mm, 18.0000 mm): Leiterbahn [3V3] auf B.Cu, Länge 84.0000 mm
    @(72.3900 mm, 34.2900 mm): Leiterbahn [I2C_SCL_3V3] auf B.Cu, Länge 1.2700 mm
[shorting_items]: Elemente, die zwei Netze kurzschließen (Netze 3V3 und I2C_SCL_3V3)
    Local override; error
    @(72.0000 mm, 18.0000 mm): Leiterbahn [3V3] auf B.Cu, Länge 84.0000 mm
    @(73.6600 mm, 34.2900 mm): Leiterbahn [I2C_SCL_3V3] auf B.Cu, Länge 1.2700 mm
[hole_clearance]: Loch-Freiraum-Verstoß (Einschränkungen aus Platinenkonfiguration zu Löchern Freiraum 0,2500 mm; tatsächlich 0,2250 mm)
    Rule: Einschränkungen aus Platinenkonfiguration zu Löchern; error
    @(8.0000 mm, 36.0000 mm): Leiterbahn [I2C_SDA_3V3] auf B.Cu, Länge 68.5400 mm
    @(6.0000 mm, 104.0000 mm): NPTH-Pad von H3
[clearance]: Freiraum-Verstoß ( Freiraum 0,2000 mm; tatsächlich 0,1900 mm)
    Local override; error
    @(8.0000 mm, 104.5400 mm): Leiterbahn [I2C_SDA_3V3] auf B.Cu, Länge 64.0000 mm
    @(70.0000 mm, 104.0000 mm): Leiterbahn [AF_RX] auf B.Cu, Länge 16.0000 mm
[tracks_crossing]: Tracks crossing
    Local override; error
    @(72.0000 mm, 18.0000 mm): Leiterbahn [3V3] auf B.Cu, Länge 84.0000 mm
    @(100.0000 mm, 36.0000 mm): Leiterbahn [I2C_SDA_3V3] auf B.Cu, Länge 92.0000 mm
[shorting_items]: Elemente, die zwei Netze kurzschließen (Netze I2C_SDA_3V3 und AF_RX)
    Local override; error
    @(72.0000 mm, 104.5400 mm): Via [I2C_SDA_3V3] auf F.Cu - B.Cu
    @(186.0000 mm, 104.0000 mm): Leiterbahn [AF_RX] auf B.Cu, Länge 116.0000 mm
[shorting_items]: Elemente, die zwei Netze kurzschließen (Netze PTT_OC und LED_TXRX_N)
    Local override; error
    @(182.0000 mm, 67.8400 mm): Durchsteckpad 3 [PTT_OC] von J_AF
    @(181.6100 mm, 66.0400 mm): Leiterbahn [LED_TXRX_N] auf F.Cu, Länge 1.2700 mm
[shorting_items]: Elemente, die zwei Netze kurzschließen (Netze PTT_OC und LED_TXRX_N)
    Local override; error
    @(182.0000 mm, 67.8400 mm): Durchsteckpad 3 [PTT_OC] von J_AF
    @(182.8800 mm, 66.0400 mm): Leiterbahn [LED_TXRX_N] auf F.Cu, Länge 1.2700 mm
[clearance]: Freiraum-Verstoß ( Freiraum 0,2000 mm; tatsächlich 0,1474 mm)
    Local override; error
    @(182.0000 mm, 67.8400 mm): Durchsteckpad 3 [PTT_OC] von J_AF
    @(184.1500 mm, 66.0400 mm): Leiterbahn [LED_TXRX_N] auf F.Cu, Länge 1.2700 mm
[clearance]: Freiraum-Verstoß ( Freiraum 0,2000 mm; tatsächlich 0,0437 mm)
    Local override; error
    @(182.8800 mm, 80.0100 mm): Leiterbahn [LED_TXRX_N] auf F.Cu, Länge 1.2700 mm
    @(182.0000 mm, 78.0000 mm): Durchsteckpad 1 [AF_TX] von J_AF
[clearance]: Freiraum-Verstoß ( Freiraum 0,2000 mm; tatsächlich 0,0350 mm)
    Local override; error
    @(182.0000 mm, 78.0000 mm): Durchsteckpad 1 [AF_TX] von J_AF
    @(181.6100 mm, 80.0100 mm): Leiterbahn [LED_TXRX_N] auf F.Cu, Länge 1.2700 mm
[clearance]: Freiraum-Verstoß ( Freiraum 0,2000 mm; tatsächlich 0,0350 mm)
    Local override; error
    @(180.3400 mm, 80.0100 mm): Leiterbahn [LED_TXRX_N] auf F.Cu, Länge 1.2700 mm
    @(182.0000 mm, 78.0000 mm): Durchsteckpad 1 [AF_TX] von J_AF
[clearance]: Freiraum-Verstoß ( Freiraum 0,2000 mm; tatsächlich 0,1050 mm)
    Local override; error
    @(36.0000 mm, 40.0000 mm): Leiterbahn [LED_PTT_N] auf B.Cu, Länge 124.0000 mm
    @(100.0000 mm, 41.0800 mm): Durchsteckpad 3 [GND] von U1
[tracks_crossing]: Tracks crossing
    Local override; error
    @(100.0000 mm, 56.3200 mm): Leiterbahn [MODEM_TXD] auf B.Cu, Länge 70.3800 mm
    @(36.0000 mm, 69.0200 mm): Leiterbahn [LED_PTT_N] auf B.Cu, Länge 29.0200 mm
[clearance]: Freiraum-Verstoß ( Freiraum 0,2000 mm; tatsächlich 0,0450 mm)
    Local override; error
    @(38.1600 mm, 68.0000 mm): Durchsteckpad 2 [+5V_OR] von R_TXR2
    @(100.0000 mm, 69.0200 mm): Leiterbahn [LED_PTT_N] auf B.Cu, Länge 64.0000 mm
[clearance]: Freiraum-Verstoß ( Freiraum 0,2000 mm; tatsächlich 0,0250 mm)
    Local override; error
    @(54.0000 mm, 63.9400 mm): Leiterbahn [PTT_DRV] auf F.Cu, Länge 45.9400 mm
    @(53.0000 mm, 34.0000 mm): Durchsteckpad 2 [GND] von C_Y2
[clearance]: Freiraum-Verstoß ( Freiraum 0,2000 mm; tatsächlich 0,1894 mm)
    Local override; error
    @(29.6200 mm, 67.2400 mm): Durchsteckpad 10 [CDL] von SKT_MODEM
    @(28.0000 mm, 68.0000 mm): Durchsteckpad 1 [TXR2_N] von R_TXR2
[clearance]: Freiraum-Verstoß ( Freiraum 0,2000 mm; tatsächlich 0,1894 mm)
    Local override; error
    @(29.6200 mm, 67.2400 mm): Durchsteckpad 10 [CDL] von SKT_MODEM
    @(28.0000 mm, 68.0000 mm): Durchsteckpad 1 [TXR2_N] von R_TXR2
[courtyards_overlap]: Courtyards overlap
    Rule: Einschränkungen aus Platinenkonfiguration zur Abstandsfläche; error
    @(182.0000 mm, 78.0000 mm): Footprint J_AF
    @(178.0000 mm, 64.0000 mm): Footprint LED_TXRX
[courtyards_overlap]: Courtyards overlap
    Rule: Einschränkungen aus Platinenkonfiguration zur Abstandsfläche; error
    @(22.0000 mm, 52.0000 mm): Footprint SKT_MODEM
    @(28.0000 mm, 68.0000 mm): Footprint R_TXR2
[pth_inside_courtyard]: PTH inside courtyard
    Local override; error
    @(28.0000 mm, 68.0000 mm): Durchsteckpad 1 [TXR2_N] von R_TXR2
    @(22.0000 mm, 52.0000 mm): Footprint SKT_MODEM
[pth_inside_courtyard]: PTH inside courtyard
    Local override; error
    @(29.6200 mm, 69.7800 mm): Durchsteckpad 9 [GND] von SKT_MODEM
    @(28.0000 mm, 68.0000 mm): Footprint R_TXR2
[pth_inside_courtyard]: PTH inside courtyard
    Local override; error
    @(29.6200 mm, 67.2400 mm): Durchsteckpad 10 [CDL] von SKT_MODEM
    @(28.0000 mm, 68.0000 mm): Footprint R_TXR2
[copper_edge_clearance]: Platinenkanten-Freiraum-Verstoß (Einschränkungen aus Platinenkonfiguration zum Rand Freiraum 0,5000 mm; tatsächlich 0,2050 mm)
    Rule: Einschränkungen aus Platinenkonfiguration zum Rand; error
    @(0.0000 mm, 0.0000 mm): Rechteck auf Edge.Cuts
    @(85.0000 mm, 107.0800 mm): Leiterbahn [I2C_SCL_5V] auf F.Cu, Länge 2.5400 mm
[copper_edge_clearance]: Platinenkanten-Freiraum-Verstoß (Einschränkungen aus Platinenkonfiguration zum Rand Freiraum 0,5000 mm; tatsächlich 0,2050 mm)
    Rule: Einschränkungen aus Platinenkonfiguration zum Rand; error
    @(0.0000 mm, 0.0000 mm): Rechteck auf Edge.Cuts
    @(85.0000 mm, 109.6200 mm): Leiterbahn [I2C_SCL_5V] auf F.Cu, Länge 15.0000 mm
[copper_edge_clearance]: Platinenkanten-Freiraum-Verstoß (Einschränkungen aus Platinenkonfiguration zum Rand Freiraum 0,5000 mm; tatsächlich 0,0000 mm)
    Rule: Einschränkungen aus Platinenkonfiguration zum Rand; error
    @(0.0000 mm, 0.0000 mm): Rechteck auf Edge.Cuts
    @(72.0000 mm, 109.6200 mm): Via [GND] auf F.Cu - B.Cu
[copper_edge_clearance]: Platinenkanten-Freiraum-Verstoß (Einschränkungen aus Platinenkonfiguration zum Rand Freiraum 0,5000 mm; tatsächlich 0,0000 mm)
    Rule: Einschränkungen aus Platinenkonfiguration zum Rand; error
    @(0.0000 mm, 0.0000 mm): Rechteck auf Edge.Cuts
    @(74.5400 mm, 109.6200 mm): Via [GND] auf F.Cu - B.Cu
[copper_edge_clearance]: Platinenkanten-Freiraum-Verstoß (Einschränkungen aus Platinenkonfiguration zum Rand Freiraum 0,5000 mm; tatsächlich 0,0000 mm)
    Rule: Einschränkungen aus Platinenkonfiguration zum Rand; error
    @(0.0000 mm, 0.0000 mm): Rechteck auf Edge.Cuts
    @(72.0000 mm, 109.6200 mm): Durchsteckpad 7 [GND] von U_LVL
[copper_edge_clearance]: Platinenkanten-Freiraum-Verstoß (Einschränkungen aus Platinenkonfiguration zum Rand Freiraum 0,5000 mm; tatsächlich 0,0000 mm)
    Rule: Einschränkungen aus Platinenkonfiguration zum Rand; error
    @(0.0000 mm, 0.0000 mm): Rechteck auf Edge.Cuts
    @(74.5400 mm, 109.6200 mm): Durchsteckpad 8 [GND] von U_LVL
[copper_edge_clearance]: Platinenkanten-Freiraum-Verstoß (Einschränkungen aus Platinenkonfiguration zum Rand Freiraum 0,5000 mm; tatsächlich 0,0000 mm)
    Rule: Einschränkungen aus Platinenkonfiguration zum Rand; error
    @(0.0000 mm, 0.0000 mm): Rechteck auf Edge.Cuts
    @(100.0000 mm, 109.6200 mm): Durchsteckpad 4 [I2C_SCL_5V] von J_LCD_I2C
[solder_mask_bridge]: Rückseitige Lötstoppöffnung über Elementen mit verschiedenen Netzen
    Rule: Mindestbreite der Lötstoppmaske aus Platinenkonfiguration; error
    @(186.0000 mm, 104.0000 mm): Leiterbahn [AF_RX] auf B.Cu, Länge 116.0000 mm
    @(100.0000 mm, 104.5400 mm): Durchsteckpad 2 [+5V_OR] von J_LCD_I2C
[solder_mask_bridge]: Rückseitige Lötstoppöffnung über Elementen mit verschiedenen Netzen
    Rule: Mindestbreite der Lötstoppmaske aus Platinenkonfiguration; error
    @(186.0000 mm, 104.0000 mm): Leiterbahn [AF_RX] auf B.Cu, Länge 116.0000 mm
    @(72.0000 mm, 104.5400 mm): Durchsteckpad 3 [I2C_SDA_3V3] von U_LVL
[solder_mask_bridge]: Rückseitige Lötstoppöffnung über Elementen mit verschiedenen Netzen
    Rule: Mindestbreite der Lötstoppmaske aus Platinenkonfiguration; error
    @(186.0000 mm, 104.0000 mm): Leiterbahn [AF_RX] auf B.Cu, Länge 116.0000 mm
    @(74.5400 mm, 104.5400 mm): Durchsteckpad 4 [I2C_SDA_5V] von U_LVL
[solder_mask_bridge]: Vorderseitige Lötstoppöffnung über Elementen mit verschiedenen Netzen
    Rule: Mindestbreite der Lötstoppmaske aus Platinenkonfiguration; error
    @(182.8800 mm, 66.0400 mm): Leiterbahn [LED_TXRX_N] auf F.Cu, Länge 1.2700 mm
    @(182.0000 mm, 67.8400 mm): Durchsteckpad 3 [PTT_OC] von J_AF
[solder_mask_bridge]: Vorderseitige Lötstoppöffnung über Elementen mit verschiedenen Netzen
    Rule: Mindestbreite der Lötstoppmaske aus Platinenkonfiguration; error
    @(181.6100 mm, 66.0400 mm): Leiterbahn [LED_TXRX_N] auf F.Cu, Länge 1.2700 mm
    @(182.0000 mm, 67.8400 mm): Durchsteckpad 3 [PTT_OC] von J_AF
[via_dangling]: Via is not connected or connected on only one layer
    Local override; warning
    @(100.0000 mm, 41.0800 mm): Via [GND] auf F.Cu - B.Cu
[via_dangling]: Via is not connected or connected on only one layer
    Local override; warning
    @(100.0000 mm, 53.7800 mm): Via [GND] auf F.Cu - B.Cu
[via_dangling]: Via is not connected or connected on only one layer
    Local override; warning
    @(100.0000 mm, 66.4800 mm): Via [GND] auf F.Cu - B.Cu
[via_dangling]: Via is not connected or connected on only one layer
    Local override; warning
    @(100.0000 mm, 79.1800 mm): Via [GND] auf F.Cu - B.Cu
[via_dangling]: Via is not connected or connected on only one layer
    Local override; warning
    @(117.7800 mm, 79.1800 mm): Via [GND] auf F.Cu - B.Cu
[via_dangling]: Via is not connected or connected on only one layer
    Local override; warning
    @(117.7800 mm, 66.4800 mm): Via [GND] auf F.Cu - B.Cu
[via_dangling]: Via is not connected or connected on only one layer
    Local override; warning
    @(117.7800 mm, 53.7800 mm): Via [GND] auf F.Cu - B.Cu
[via_dangling]: Via is not connected or connected on only one layer
    Local override; warning
    @(117.7800 mm, 41.0800 mm): Via [GND] auf F.Cu - B.Cu
[via_dangling]: Via is not connected or connected on only one layer
    Local override; warning
    @(29.6200 mm, 69.7800 mm): Via [GND] auf F.Cu - B.Cu
[via_dangling]: Via is not connected or connected on only one layer
    Local override; warning
    @(15.0000 mm, 8.0000 mm): Via [GND] auf F.Cu - B.Cu
[via_dangling]: Via is not connected or connected on only one layer
    Local override; warning
    @(25.0700 mm, 5.2900 mm): Via [GND] auf F.Cu - B.Cu
[via_dangling]: Via is not connected or connected on only one layer
    Local override; warning
    @(11.9300 mm, 5.2900 mm): Via [GND] auf F.Cu - B.Cu
[via_dangling]: Via is not connected or connected on only one layer
    Local override; warning
    @(48.0000 mm, 29.6200 mm): Via [GND] auf F.Cu - B.Cu
[via_dangling]: Via is not connected or connected on only one layer
    Local override; warning
    @(74.0000 mm, 6.0000 mm): Via [GND] auf F.Cu - B.Cu
[via_dangling]: Via is not connected or connected on only one layer
    Local override; warning
    @(69.3000 mm, 9.0000 mm): Via [GND] auf F.Cu - B.Cu
[via_dangling]: Via is not connected or connected on only one layer
    Local override; warning
    @(140.0000 mm, 16.5400 mm): Via [GND] auf F.Cu - B.Cu
[via_dangling]: Via is not connected or connected on only one layer
    Local override; warning
    @(129.5000 mm, 12.0000 mm): Via [GND] auf F.Cu - B.Cu
[via_dangling]: Via is not connected or connected on only one layer
    Local override; warning
    @(185.5000 mm, 14.0000 mm): Via [GND] auf F.Cu - B.Cu
[via_dangling]: Via is not connected or connected on only one layer
    Local override; warning
    @(27.0000 mm, 76.0000 mm): Via [GND] auf F.Cu - B.Cu
[via_dangling]: Via is not connected or connected on only one layer
    Local override; warning
    @(87.0000 mm, 30.0000 mm): Via [GND] auf F.Cu - B.Cu
[via_dangling]: Via is not connected or connected on only one layer
    Local override; warning
    @(37.0000 mm, 34.0000 mm): Via [GND] auf F.Cu - B.Cu
[via_dangling]: Via is not connected or connected on only one layer
    Local override; warning
    @(53.0000 mm, 34.0000 mm): Via [GND] auf F.Cu - B.Cu
[via_dangling]: Via is not connected or connected on only one layer
    Local override; warning
    @(52.1600 mm, 62.0000 mm): Via [GND] auf F.Cu - B.Cu
[via_dangling]: Via is not connected or connected on only one layer
    Local override; warning
    @(52.1600 mm, 54.0000 mm): Via [GND] auf F.Cu - B.Cu
[via_dangling]: Via is not connected or connected on only one layer
    Local override; warning
    @(182.0000 mm, 62.7600 mm): Via [GND] auf F.Cu - B.Cu
[via_dangling]: Via is not connected or connected on only one layer
    Local override; warning
    @(52.9200 mm, 80.0000 mm): Via [GND] auf F.Cu - B.Cu
[via_dangling]: Via is not connected or connected on only one layer
    Local override; warning
    @(52.9200 mm, 94.0000 mm): Via [GND] auf F.Cu - B.Cu
[via_dangling]: Via is not connected or connected on only one layer
    Local override; warning
    @(178.0000 mm, 28.0000 mm): Via [GND] auf F.Cu - B.Cu
[via_dangling]: Via is not connected or connected on only one layer
    Local override; warning
    @(178.0000 mm, 40.0000 mm): Via [GND] auf F.Cu - B.Cu
[via_dangling]: Via is not connected or connected on only one layer
    Local override; warning
    @(178.0000 mm, 52.0000 mm): Via [GND] auf F.Cu - B.Cu
[via_dangling]: Via is not connected or connected on only one layer
    Local override; warning
    @(178.0000 mm, 64.0000 mm): Via [GND] auf F.Cu - B.Cu
[via_dangling]: Via is not connected or connected on only one layer
    Local override; warning
    @(98.0000 mm, 12.0000 mm): Via [GND] auf F.Cu - B.Cu
[via_dangling]: Via is not connected or connected on only one layer
    Local override; warning
    @(72.0000 mm, 109.6200 mm): Via [GND] auf F.Cu - B.Cu
[via_dangling]: Via is not connected or connected on only one layer
    Local override; warning
    @(74.5400 mm, 109.6200 mm): Via [GND] auf F.Cu - B.Cu
[via_dangling]: Via is not connected or connected on only one layer
    Local override; warning
    @(100.0000 mm, 102.0000 mm): Via [GND] auf F.Cu - B.Cu
[via_dangling]: Via is not connected or connected on only one layer
    Local override; warning
    @(122.9200 mm, 100.0000 mm): Via [GND] auf F.Cu - B.Cu
[silk_edge_clearance]: Silkscreen clipped by board edge
    Rule: Einschränkungen aus Platinenkonfiguration zum Bestückungsdruck; warning
    @(0.0000 mm, 0.0000 mm): Rechteck auf Edge.Cuts
    @(25.1600 mm, -4.5800 mm): Abschnitt von J_USB auf F.Silkscreen
[silk_edge_clearance]: Silkscreen clipped by board edge
    Rule: Einschränkungen aus Platinenkonfiguration zum Bestückungsdruck; warning
    @(0.0000 mm, 0.0000 mm): Rechteck auf Edge.Cuts
    @(11.8400 mm, 3.5300 mm): Abschnitt von J_USB auf F.Silkscreen
[silk_edge_clearance]: Silkscreen clipped by board edge
    Rule: Einschränkungen aus Platinenkonfiguration zum Bestückungsdruck; warning
    @(0.0000 mm, 0.0000 mm): Rechteck auf Edge.Cuts
    @(78.6000 mm, -1.8000 mm): Abschnitt von J_DC auf F.Silkscreen
[silk_edge_clearance]: Silkscreen clipped by board edge
    Rule: Einschränkungen aus Platinenkonfiguration zum Bestückungsdruck; warning
    @(0.0000 mm, 0.0000 mm): Rechteck auf Edge.Cuts
    @(69.4000 mm, 7.0000 mm): Abschnitt von J_DC auf F.Silkscreen
[silk_edge_clearance]: Silkscreen clipped by board edge
    Rule: Einschränkungen aus Platinenkonfiguration zum Bestückungsdruck; warning
    @(0.0000 mm, 0.0000 mm): Rechteck auf Edge.Cuts
    @(179.8900 mm, 81.6500 mm): Rechteck von J_AF auf F.Silkscreen
[silk_edge_clearance]: Silkscreen clipped by board edge
    Rule: Einschränkungen aus Platinenkonfiguration zum Bestückungsdruck; warning
    @(0.0000 mm, 0.0000 mm): Rechteck auf Edge.Cuts
    @(188.8100 mm, 81.6500 mm): Rechteck von J_AF auf F.Silkscreen
[silk_edge_clearance]: Silkscreen clipped by board edge
    Rule: Einschränkungen aus Platinenkonfiguration zum Bestückungsdruck; warning
    @(0.0000 mm, 0.0000 mm): Rechteck auf Edge.Cuts
    @(70.6200 mm, 103.2700 mm): Abschnitt von U_LVL auf F.Silkscreen
[silk_edge_clearance]: Silkscreen clipped by board edge
    Rule: Einschränkungen aus Platinenkonfiguration zum Bestückungsdruck; warning
    @(0.0000 mm, 0.0000 mm): Rechteck auf Edge.Cuts
    @(75.9200 mm, 100.6200 mm): Abschnitt von U_LVL auf F.Silkscreen
[silk_edge_clearance]: Silkscreen clipped by board edge
    Rule: Einschränkungen aus Platinenkonfiguration zum Bestückungsdruck; warning
    @(0.0000 mm, 0.0000 mm): Rechteck auf Edge.Cuts
    @(98.6200 mm, 103.2700 mm): Abschnitt von J_LCD_I2C auf F.Silkscreen
[silk_edge_clearance]: Silkscreen clipped by board edge
    Rule: Einschränkungen aus Platinenkonfiguration zum Bestückungsdruck; warning
    @(0.0000 mm, 0.0000 mm): Rechteck auf Edge.Cuts
    @(101.3800 mm, 103.2700 mm): Abschnitt von J_LCD_I2C auf F.Silkscreen
[holes_co_located]: Drilled holes co-located
    Local override; warning
    @(100.0000 mm, 69.0200 mm): Via [LED_PTT_N] auf F.Cu - B.Cu
    @(100.0000 mm, 69.0200 mm): Durchsteckpad 14 [LED_PTT_N] von U1
[holes_co_located]: Drilled holes co-located
    Local override; warning
    @(160.0000 mm, 40.0000 mm): Via [LED_PTT_N] auf F.Cu - B.Cu
    @(160.0000 mm, 40.0000 mm): Durchsteckpad 1 [LED_PTT_N] von R_LED2
[holes_co_located]: Drilled holes co-located
    Local override; warning
    @(100.0000 mm, 71.5600 mm): Via [LED_DCD_N] auf F.Cu - B.Cu
    @(100.0000 mm, 71.5600 mm): Durchsteckpad 15 [LED_DCD_N] von U1
[holes_co_located]: Drilled holes co-located
    Local override; warning
    @(160.0000 mm, 52.0000 mm): Durchsteckpad 1 [LED_DCD_N] von R_LED3
    @(160.0000 mm, 52.0000 mm): Via [LED_DCD_N] auf F.Cu - B.Cu
[holes_co_located]: Drilled holes co-located
    Local override; warning
    @(100.0000 mm, 36.0000 mm): Durchsteckpad 1 [I2C_SDA_3V3] von U1
    @(100.0000 mm, 36.0000 mm): Via [I2C_SDA_3V3] auf F.Cu - B.Cu
[holes_co_located]: Drilled holes co-located
    Local override; warning
    @(72.0000 mm, 104.5400 mm): Via [I2C_SDA_3V3] auf F.Cu - B.Cu
    @(72.0000 mm, 104.5400 mm): Durchsteckpad 3 [I2C_SDA_3V3] von U_LVL
[holes_co_located]: Drilled holes co-located
    Local override; warning
    @(100.0000 mm, 38.5400 mm): Via [I2C_SCL_3V3] auf F.Cu - B.Cu
    @(100.0000 mm, 38.5400 mm): Durchsteckpad 2 [I2C_SCL_3V3] von U1
[holes_co_located]: Drilled holes co-located
    Local override; warning
    @(72.0000 mm, 107.0800 mm): Durchsteckpad 5 [I2C_SCL_3V3] von U_LVL
    @(72.0000 mm, 107.0800 mm): Via [I2C_SCL_3V3] auf F.Cu - B.Cu
[holes_co_located]: Drilled holes co-located
    Local override; warning
    @(22.0000 mm, 59.6200 mm): Durchsteckpad 4 [RXA] von SKT_MODEM
    @(22.0000 mm, 59.6200 mm): Via [RXA] auf F.Cu - B.Cu
[holes_co_located]: Drilled holes co-located
    Local override; warning
    @(75.0000 mm, 88.0000 mm): Durchsteckpad 2 [RXA] von C_RX
    @(75.0000 mm, 88.0000 mm): Via [RXA] auf F.Cu - B.Cu
[holes_co_located]: Drilled holes co-located
    Local override; warning
    @(29.6200 mm, 64.7000 mm): Via [TXA] auf F.Cu - B.Cu
    @(29.6200 mm, 64.7000 mm): Durchsteckpad 11 [TXA] von SKT_MODEM
[holes_co_located]: Drilled holes co-located
    Local override; warning
    @(58.0000 mm, 80.0000 mm): Durchsteckpad 1 [TXA] von RV1
    @(58.0000 mm, 80.0000 mm): Via [TXA] auf F.Cu - B.Cu
[holes_co_located]: Drilled holes co-located
    Local override; warning
    @(22.0000 mm, 67.2400 mm): Via [CDL] auf F.Cu - B.Cu
    @(22.0000 mm, 67.2400 mm): Durchsteckpad 7 [CDL] von SKT_MODEM
[holes_co_located]: Drilled holes co-located
    Local override; warning
    @(29.6200 mm, 67.2400 mm): Durchsteckpad 10 [CDL] von SKT_MODEM
    @(29.6200 mm, 67.2400 mm): Via [CDL] auf F.Cu - B.Cu
[holes_co_located]: Drilled holes co-located
    Local override; warning
    @(29.6200 mm, 67.2400 mm): Via [CDL] auf F.Cu - B.Cu
    @(29.6200 mm, 67.2400 mm): Via [CDL] auf F.Cu - B.Cu
[holes_co_located]: Drilled holes co-located
    Local override; warning
    @(29.6200 mm, 67.2400 mm): Via [CDL] auf F.Cu - B.Cu
    @(29.6200 mm, 67.2400 mm): Durchsteckpad 10 [CDL] von SKT_MODEM
[holes_co_located]: Drilled holes co-located
    Local override; warning
    @(55.4600 mm, 94.0000 mm): Via [CDL] auf F.Cu - B.Cu
    @(55.4600 mm, 94.0000 mm): Durchsteckpad 2 [CDL] von RV_CDL
[holes_co_located]: Drilled holes co-located
    Local override; warning
    @(22.0000 mm, 8.0000 mm): Via [VBUS] auf F.Cu - B.Cu
    @(22.0000 mm, 8.0000 mm): Durchsteckpad 1 [VBUS] von J_USB
[holes_co_located]: Drilled holes co-located
    Local override; warning
    @(48.0000 mm, 22.0000 mm): Via [VBUS] auf F.Cu - B.Cu
    @(48.0000 mm, 22.0000 mm): Via [VBUS] auf F.Cu - B.Cu
[holes_co_located]: Drilled holes co-located
    Local override; warning
    @(48.0000 mm, 22.0000 mm): Via [VBUS] auf F.Cu - B.Cu
    @(48.0000 mm, 22.0000 mm): Durchsteckpad 1 [VBUS] von J_USB_PICO
[holes_co_located]: Drilled holes co-located
    Local override; warning
    @(48.0000 mm, 22.0000 mm): Via [VBUS] auf F.Cu - B.Cu
    @(48.0000 mm, 22.0000 mm): Durchsteckpad 1 [VBUS] von J_USB_PICO
[holes_co_located]: Drilled holes co-located
    Local override; warning
    @(168.1600 mm, 24.0000 mm): Durchsteckpad 2 [VBUS] von D_OR2
    @(168.1600 mm, 24.0000 mm): Via [VBUS] auf F.Cu - B.Cu
[holes_co_located]: Drilled holes co-located
    Local override; warning
    @(100.0000 mm, 56.3200 mm): Durchsteckpad 9 [MODEM_TXD] von U1
    @(100.0000 mm, 56.3200 mm): Via [MODEM_TXD] auf F.Cu - B.Cu
[holes_co_located]: Drilled holes co-located
    Local override; warning
    @(29.6200 mm, 57.0800 mm): Via [MODEM_TXD] auf F.Cu - B.Cu
    @(29.6200 mm, 57.0800 mm): Durchsteckpad 14 [MODEM_TXD] von SKT_MODEM
[holes_co_located]: Drilled holes co-located
    Local override; warning
    @(100.0000 mm, 58.8600 mm): Durchsteckpad 10 [MODEM_RXD] von U1
    @(100.0000 mm, 58.8600 mm): Via [MODEM_RXD] auf F.Cu - B.Cu
[holes_co_located]: Drilled holes co-located
    Local override; warning
    @(22.0000 mm, 69.7800 mm): Durchsteckpad 8 [MODEM_RXD] von SKT_MODEM
    @(22.0000 mm, 69.7800 mm): Via [MODEM_RXD] auf F.Cu - B.Cu
[holes_co_located]: Drilled holes co-located
    Local override; warning
    @(100.0000 mm, 61.4000 mm): Via [MODEM_CDT] auf F.Cu - B.Cu
    @(100.0000 mm, 61.4000 mm): Durchsteckpad 11 [MODEM_CDT] von U1
[holes_co_located]: Drilled holes co-located
    Local override; warning
    @(22.0000 mm, 57.0800 mm): Via [MODEM_CDT] auf F.Cu - B.Cu
    @(22.0000 mm, 57.0800 mm): Durchsteckpad 3 [MODEM_CDT] von SKT_MODEM
[holes_co_located]: Drilled holes co-located
    Local override; warning
    @(117.7800 mm, 46.1600 mm): Durchsteckpad 36 [3V3] von U1
    @(117.7800 mm, 46.1600 mm): Via [3V3] auf F.Cu - B.Cu
[holes_co_located]: Drilled holes co-located
    Local override; warning
    @(72.0000 mm, 102.0000 mm): Via [3V3] auf F.Cu - B.Cu
    @(72.0000 mm, 102.0000 mm): Durchsteckpad 1 [3V3] von U_LVL
[holes_co_located]: Drilled holes co-located
    Local override; warning
    @(182.0000 mm, 72.9200 mm): Via [AF_RX] auf F.Cu - B.Cu
    @(182.0000 mm, 72.9200 mm): Durchsteckpad 2 [AF_RX] von J_AF
[holes_co_located]: Drilled holes co-located
    Local override; warning
    @(70.0000 mm, 88.0000 mm): Via [AF_RX] auf F.Cu - B.Cu
    @(70.0000 mm, 88.0000 mm): Durchsteckpad 1 [AF_RX] von C_RX
[holes_co_located]: Drilled holes co-located
    Local override; warning
    @(100.0000 mm, 41.0800 mm): Via [GND] auf F.Cu - B.Cu
    @(100.0000 mm, 41.0800 mm): Durchsteckpad 3 [GND] von U1
[holes_co_located]: Drilled holes co-located
    Local override; warning
    @(100.0000 mm, 53.7800 mm): Durchsteckpad 8 [GND] von U1
    @(100.0000 mm, 53.7800 mm): Via [GND] auf F.Cu - B.Cu
[holes_co_located]: Drilled holes co-located
    Local override; warning
    @(100.0000 mm, 66.4800 mm): Durchsteckpad 13 [GND] von U1
    @(100.0000 mm, 66.4800 mm): Via [GND] auf F.Cu - B.Cu
[holes_co_located]: Drilled holes co-located
    Local override; warning
    @(100.0000 mm, 79.1800 mm): Via [GND] auf F.Cu - B.Cu
    @(100.0000 mm, 79.1800 mm): Durchsteckpad 18 [GND] von U1
[holes_co_located]: Drilled holes co-located
    Local override; warning
    @(117.7800 mm, 79.1800 mm): Durchsteckpad 23 [GND] von U1
    @(117.7800 mm, 79.1800 mm): Via [GND] auf F.Cu - B.Cu
[holes_co_located]: Drilled holes co-located
    Local override; warning
    @(117.7800 mm, 66.4800 mm): Durchsteckpad 28 [GND] von U1
    @(117.7800 mm, 66.4800 mm): Via [GND] auf F.Cu - B.Cu
[holes_co_located]: Drilled holes co-located
    Local override; warning
    @(117.7800 mm, 53.7800 mm): Durchsteckpad 33 [GND] von U1
    @(117.7800 mm, 53.7800 mm): Via [GND] auf F.Cu - B.Cu
[holes_co_located]: Drilled holes co-located
    Local override; warning
    @(117.7800 mm, 41.0800 mm): Via [GND] auf F.Cu - B.Cu
    @(117.7800 mm, 41.0800 mm): Durchsteckpad 38 [GND] von U1
[holes_co_located]: Drilled holes co-located
    Local override; warning
    @(29.6200 mm, 69.7800 mm): Durchsteckpad 9 [GND] von SKT_MODEM
    @(29.6200 mm, 69.7800 mm): Via [GND] auf F.Cu - B.Cu
[holes_co_located]: Drilled holes co-located
    Local override; warning
    @(15.0000 mm, 8.0000 mm): Durchsteckpad 4 [GND] von J_USB
    @(15.0000 mm, 8.0000 mm): Via [GND] auf F.Cu - B.Cu
[holes_co_located]: Drilled holes co-located
    Local override; warning
    @(25.0700 mm, 5.2900 mm): Durchsteckpad SH [GND] von J_USB
    @(25.0700 mm, 5.2900 mm): Via [GND] auf F.Cu - B.Cu
[holes_co_located]: Drilled holes co-located
    Local override; warning
    @(11.9300 mm, 5.2900 mm): Durchsteckpad SH [GND] von J_USB
    @(11.9300 mm, 5.2900 mm): Via [GND] auf F.Cu - B.Cu
[holes_co_located]: Drilled holes co-located
    Local override; warning
    @(48.0000 mm, 29.6200 mm): Via [GND] auf F.Cu - B.Cu
    @(48.0000 mm, 29.6200 mm): Durchsteckpad 4 [GND] von J_USB_PICO
[holes_co_located]: Drilled holes co-located
    Local override; warning
    @(140.0000 mm, 16.5400 mm): Via [GND] auf F.Cu - B.Cu
    @(140.0000 mm, 16.5400 mm): Durchsteckpad 2 [GND] von U_REG
[holes_co_located]: Drilled holes co-located
    Local override; warning
    @(129.5000 mm, 12.0000 mm): Durchsteckpad 2 [GND] von C_IN
    @(129.5000 mm, 12.0000 mm): Via [GND] auf F.Cu - B.Cu
[holes_co_located]: Drilled holes co-located
    Local override; warning
    @(185.5000 mm, 14.0000 mm): Durchsteckpad 2 [GND] von C_BULK
    @(185.5000 mm, 14.0000 mm): Via [GND] auf F.Cu - B.Cu
[holes_co_located]: Drilled holes co-located
    Local override; warning
    @(27.0000 mm, 76.0000 mm): Durchsteckpad 2 [GND] von C_BYP1
    @(27.0000 mm, 76.0000 mm): Via [GND] auf F.Cu - B.Cu
[holes_co_located]: Drilled holes co-located
    Local override; warning
    @(87.0000 mm, 30.0000 mm): Via [GND] auf F.Cu - B.Cu
    @(87.0000 mm, 30.0000 mm): Durchsteckpad 2 [GND] von C_BYP2
[holes_co_located]: Drilled holes co-located
    Local override; warning
    @(37.0000 mm, 34.0000 mm): Durchsteckpad 2 [GND] von C_Y1
    @(37.0000 mm, 34.0000 mm): Via [GND] auf F.Cu - B.Cu
[holes_co_located]: Drilled holes co-located
    Local override; warning
    @(53.0000 mm, 34.0000 mm): Via [GND] auf F.Cu - B.Cu
    @(53.0000 mm, 34.0000 mm): Durchsteckpad 2 [GND] von C_Y2
[holes_co_located]: Drilled holes co-located
    Local override; warning
    @(52.1600 mm, 62.0000 mm): Durchsteckpad 2 [GND] von R_TXR1
    @(52.1600 mm, 62.0000 mm): Via [GND] auf F.Cu - B.Cu
[holes_co_located]: Drilled holes co-located
    Local override; warning
    @(52.1600 mm, 54.0000 mm): Durchsteckpad 2 [GND] von R_TRS
    @(52.1600 mm, 54.0000 mm): Via [GND] auf F.Cu - B.Cu
[holes_co_located]: Drilled holes co-located
    Local override; warning
    @(182.0000 mm, 62.7600 mm): Via [GND] auf F.Cu - B.Cu
    @(182.0000 mm, 62.7600 mm): Durchsteckpad 4 [GND] von J_AF
[holes_co_located]: Drilled holes co-located
    Local override; warning
    @(52.9200 mm, 80.0000 mm): Via [GND] auf F.Cu - B.Cu
    @(52.9200 mm, 80.0000 mm): Durchsteckpad 3 [GND] von RV1
[holes_co_located]: Drilled holes co-located
    Local override; warning
    @(52.9200 mm, 94.0000 mm): Via [GND] auf F.Cu - B.Cu
    @(52.9200 mm, 94.0000 mm): Durchsteckpad 3 [GND] von RV_CDL
[holes_co_located]: Drilled holes co-located
    Local override; warning
    @(148.0000 mm, 58.0000 mm): Durchsteckpad 1 [GND] von Q1
    @(148.0000 mm, 58.0000 mm): Via [GND] auf F.Cu - B.Cu
[holes_co_located]: Drilled holes co-located
    Local override; warning
    @(178.0000 mm, 28.0000 mm): Via [GND] auf F.Cu - B.Cu
    @(178.0000 mm, 28.0000 mm): Durchsteckpad 1 [GND] von LED_PWR
[holes_co_located]: Drilled holes co-located
    Local override; warning
    @(178.0000 mm, 40.0000 mm): Durchsteckpad 1 [GND] von LED_PTT
    @(178.0000 mm, 40.0000 mm): Via [GND] auf F.Cu - B.Cu
[holes_co_located]: Drilled holes co-located
    Local override; warning
    @(178.0000 mm, 52.0000 mm): Via [GND] auf F.Cu - B.Cu
    @(178.0000 mm, 52.0000 mm): Durchsteckpad 1 [GND] von LED_DCD
[holes_co_located]: Drilled holes co-located
    Local override; warning
    @(178.0000 mm, 64.0000 mm): Via [GND] auf F.Cu - B.Cu
    @(178.0000 mm, 64.0000 mm): Durchsteckpad 1 [GND] von LED_TXRX
[holes_co_located]: Drilled holes co-located
    Local override; warning
    @(98.0000 mm, 12.0000 mm): Durchsteckpad 1 [GND] von SW1
    @(98.0000 mm, 12.0000 mm): Via [GND] auf F.Cu - B.Cu
[holes_co_located]: Drilled holes co-located
    Local override; warning
    @(72.0000 mm, 109.6200 mm): Durchsteckpad 7 [GND] von U_LVL
    @(72.0000 mm, 109.6200 mm): Via [GND] auf F.Cu - B.Cu
[holes_co_located]: Drilled holes co-located
    Local override; warning
    @(74.5400 mm, 109.6200 mm): Durchsteckpad 8 [GND] von U_LVL
    @(74.5400 mm, 109.6200 mm): Via [GND] auf F.Cu - B.Cu
[holes_co_located]: Drilled holes co-located
    Local override; warning
    @(100.0000 mm, 102.0000 mm): Durchsteckpad 1 [GND] von J_LCD_I2C
    @(100.0000 mm, 102.0000 mm): Via [GND] auf F.Cu - B.Cu
[holes_co_located]: Drilled holes co-located
    Local override; warning
    @(122.9200 mm, 100.0000 mm): Via [GND] auf F.Cu - B.Cu
    @(122.9200 mm, 100.0000 mm): Durchsteckpad 3 [GND] von RV2
[holes_co_located]: Drilled holes co-located
    Local override; warning
    @(22.0000 mm, 8.0000 mm): Via [VBUS] auf F.Cu - B.Cu
    @(22.0000 mm, 8.0000 mm): Durchsteckpad 1 [VBUS] von J_USB
[holes_co_located]: Drilled holes co-located
    Local override; warning
    @(15.0000 mm, 8.0000 mm): Durchsteckpad 4 [GND] von J_USB
    @(15.0000 mm, 8.0000 mm): Via [GND] auf F.Cu - B.Cu
[holes_co_located]: Drilled holes co-located
    Local override; warning
    @(25.0700 mm, 5.2900 mm): Durchsteckpad SH [GND] von J_USB
    @(25.0700 mm, 5.2900 mm): Via [GND] auf F.Cu - B.Cu
[holes_co_located]: Drilled holes co-located
    Local override; warning
    @(11.9300 mm, 5.2900 mm): Durchsteckpad SH [GND] von J_USB
    @(11.9300 mm, 5.2900 mm): Via [GND] auf F.Cu - B.Cu
[holes_co_located]: Drilled holes co-located
    Local override; warning
    @(48.0000 mm, 22.0000 mm): Via [VBUS] auf F.Cu - B.Cu
    @(48.0000 mm, 22.0000 mm): Durchsteckpad 1 [VBUS] von J_USB_PICO
[holes_co_located]: Drilled holes co-located
    Local override; warning
    @(48.0000 mm, 22.0000 mm): Via [VBUS] auf F.Cu - B.Cu
    @(48.0000 mm, 22.0000 mm): Durchsteckpad 1 [VBUS] von J_USB_PICO
[holes_co_located]: Drilled holes co-located
    Local override; warning
    @(48.0000 mm, 29.6200 mm): Via [GND] auf F.Cu - B.Cu
    @(48.0000 mm, 29.6200 mm): Durchsteckpad 4 [GND] von J_USB_PICO
[holes_co_located]: Drilled holes co-located
    Local override; warning
    @(98.0000 mm, 12.0000 mm): Durchsteckpad 1 [GND] von SW1
    @(98.0000 mm, 12.0000 mm): Via [GND] auf F.Cu - B.Cu
[holes_co_located]: Drilled holes co-located
    Local override; warning
    @(129.5000 mm, 12.0000 mm): Durchsteckpad 2 [GND] von C_IN
    @(129.5000 mm, 12.0000 mm): Via [GND] auf F.Cu - B.Cu
[holes_co_located]: Drilled holes co-located
    Local override; warning
    @(140.0000 mm, 16.5400 mm): Via [GND] auf F.Cu - B.Cu
    @(140.0000 mm, 16.5400 mm): Durchsteckpad 2 [GND] von U_REG
[holes_co_located]: Drilled holes co-located
    Local override; warning
    @(168.1600 mm, 24.0000 mm): Durchsteckpad 2 [VBUS] von D_OR2
    @(168.1600 mm, 24.0000 mm): Via [VBUS] auf F.Cu - B.Cu
[holes_co_located]: Drilled holes co-located
    Local override; warning
    @(185.5000 mm, 14.0000 mm): Durchsteckpad 2 [GND] von C_BULK
    @(185.5000 mm, 14.0000 mm): Via [GND] auf F.Cu - B.Cu
[holes_co_located]: Drilled holes co-located
    Local override; warning
    @(100.0000 mm, 36.0000 mm): Durchsteckpad 1 [I2C_SDA_3V3] von U1
    @(100.0000 mm, 36.0000 mm): Via [I2C_SDA_3V3] auf F.Cu - B.Cu
[holes_co_located]: Drilled holes co-located
    Local override; warning
    @(100.0000 mm, 38.5400 mm): Via [I2C_SCL_3V3] auf F.Cu - B.Cu
    @(100.0000 mm, 38.5400 mm): Durchsteckpad 2 [I2C_SCL_3V3] von U1
[holes_co_located]: Drilled holes co-located
    Local override; warning
    @(100.0000 mm, 41.0800 mm): Via [GND] auf F.Cu - B.Cu
    @(100.0000 mm, 41.0800 mm): Durchsteckpad 3 [GND] von U1
[holes_co_located]: Drilled holes co-located
    Local override; warning
    @(100.0000 mm, 53.7800 mm): Durchsteckpad 8 [GND] von U1
    @(100.0000 mm, 53.7800 mm): Via [GND] auf F.Cu - B.Cu
[holes_co_located]: Drilled holes co-located
    Local override; warning
    @(100.0000 mm, 56.3200 mm): Durchsteckpad 9 [MODEM_TXD] von U1
    @(100.0000 mm, 56.3200 mm): Via [MODEM_TXD] auf F.Cu - B.Cu
[holes_co_located]: Drilled holes co-located
    Local override; warning
    @(100.0000 mm, 58.8600 mm): Durchsteckpad 10 [MODEM_RXD] von U1
    @(100.0000 mm, 58.8600 mm): Via [MODEM_RXD] auf F.Cu - B.Cu
[holes_co_located]: Drilled holes co-located
    Local override; warning
    @(100.0000 mm, 61.4000 mm): Via [MODEM_CDT] auf F.Cu - B.Cu
    @(100.0000 mm, 61.4000 mm): Durchsteckpad 11 [MODEM_CDT] von U1
[holes_co_located]: Drilled holes co-located
    Local override; warning
    @(100.0000 mm, 66.4800 mm): Durchsteckpad 13 [GND] von U1
    @(100.0000 mm, 66.4800 mm): Via [GND] auf F.Cu - B.Cu
[holes_co_located]: Drilled holes co-located
    Local override; warning
    @(100.0000 mm, 69.0200 mm): Via [LED_PTT_N] auf F.Cu - B.Cu
    @(100.0000 mm, 69.0200 mm): Durchsteckpad 14 [LED_PTT_N] von U1
[holes_co_located]: Drilled holes co-located
    Local override; warning
    @(100.0000 mm, 71.5600 mm): Via [LED_DCD_N] auf F.Cu - B.Cu
    @(100.0000 mm, 71.5600 mm): Durchsteckpad 15 [LED_DCD_N] von U1
[holes_co_located]: Drilled holes co-located
    Local override; warning
    @(100.0000 mm, 79.1800 mm): Via [GND] auf F.Cu - B.Cu
    @(100.0000 mm, 79.1800 mm): Durchsteckpad 18 [GND] von U1
[holes_co_located]: Drilled holes co-located
    Local override; warning
    @(117.7800 mm, 79.1800 mm): Durchsteckpad 23 [GND] von U1
    @(117.7800 mm, 79.1800 mm): Via [GND] auf F.Cu - B.Cu
[holes_co_located]: Drilled holes co-located
    Local override; warning
    @(117.7800 mm, 66.4800 mm): Durchsteckpad 28 [GND] von U1
    @(117.7800 mm, 66.4800 mm): Via [GND] auf F.Cu - B.Cu
[holes_co_located]: Drilled holes co-located
    Local override; warning
    @(117.7800 mm, 53.7800 mm): Durchsteckpad 33 [GND] von U1
    @(117.7800 mm, 53.7800 mm): Via [GND] auf F.Cu - B.Cu
[holes_co_located]: Drilled holes co-located
    Local override; warning
    @(117.7800 mm, 46.1600 mm): Durchsteckpad 36 [3V3] von U1
    @(117.7800 mm, 46.1600 mm): Via [3V3] auf F.Cu - B.Cu
[holes_co_located]: Drilled holes co-located
    Local override; warning
    @(117.7800 mm, 41.0800 mm): Via [GND] auf F.Cu - B.Cu
    @(117.7800 mm, 41.0800 mm): Durchsteckpad 38 [GND] von U1
[holes_co_located]: Drilled holes co-located
    Local override; warning
    @(87.0000 mm, 30.0000 mm): Via [GND] auf F.Cu - B.Cu
    @(87.0000 mm, 30.0000 mm): Durchsteckpad 2 [GND] von C_BYP2
[holes_co_located]: Drilled holes co-located
    Local override; warning
    @(22.0000 mm, 57.0800 mm): Via [MODEM_CDT] auf F.Cu - B.Cu
    @(22.0000 mm, 57.0800 mm): Durchsteckpad 3 [MODEM_CDT] von SKT_MODEM
[holes_co_located]: Drilled holes co-located
    Local override; warning
    @(22.0000 mm, 59.6200 mm): Durchsteckpad 4 [RXA] von SKT_MODEM
    @(22.0000 mm, 59.6200 mm): Via [RXA] auf F.Cu - B.Cu
[holes_co_located]: Drilled holes co-located
    Local override; warning
    @(22.0000 mm, 67.2400 mm): Via [CDL] auf F.Cu - B.Cu
    @(22.0000 mm, 67.2400 mm): Durchsteckpad 7 [CDL] von SKT_MODEM
[holes_co_located]: Drilled holes co-located
    Local override; warning
    @(22.0000 mm, 69.7800 mm): Durchsteckpad 8 [MODEM_RXD] von SKT_MODEM
    @(22.0000 mm, 69.7800 mm): Via [MODEM_RXD] auf F.Cu - B.Cu
[holes_co_located]: Drilled holes co-located
    Local override; warning
    @(29.6200 mm, 69.7800 mm): Durchsteckpad 9 [GND] von SKT_MODEM
    @(29.6200 mm, 69.7800 mm): Via [GND] auf F.Cu - B.Cu
[holes_co_located]: Drilled holes co-located
    Local override; warning
    @(29.6200 mm, 67.2400 mm): Durchsteckpad 10 [CDL] von SKT_MODEM
    @(29.6200 mm, 67.2400 mm): Via [CDL] auf F.Cu - B.Cu
[holes_co_located]: Drilled holes co-located
    Local override; warning
    @(29.6200 mm, 67.2400 mm): Via [CDL] auf F.Cu - B.Cu
    @(29.6200 mm, 67.2400 mm): Durchsteckpad 10 [CDL] von SKT_MODEM
[holes_co_located]: Drilled holes co-located
    Local override; warning
    @(29.6200 mm, 64.7000 mm): Via [TXA] auf F.Cu - B.Cu
    @(29.6200 mm, 64.7000 mm): Durchsteckpad 11 [TXA] von SKT_MODEM
[holes_co_located]: Drilled holes co-located
    Local override; warning
    @(29.6200 mm, 57.0800 mm): Via [MODEM_TXD] auf F.Cu - B.Cu
    @(29.6200 mm, 57.0800 mm): Durchsteckpad 14 [MODEM_TXD] von SKT_MODEM
[holes_co_located]: Drilled holes co-located
    Local override; warning
    @(37.0000 mm, 34.0000 mm): Durchsteckpad 2 [GND] von C_Y1
    @(37.0000 mm, 34.0000 mm): Via [GND] auf F.Cu - B.Cu
[holes_co_located]: Drilled holes co-located
    Local override; warning
    @(53.0000 mm, 34.0000 mm): Via [GND] auf F.Cu - B.Cu
    @(53.0000 mm, 34.0000 mm): Durchsteckpad 2 [GND] von C_Y2
[holes_co_located]: Drilled holes co-located
    Local override; warning
    @(27.0000 mm, 76.0000 mm): Durchsteckpad 2 [GND] von C_BYP1
    @(27.0000 mm, 76.0000 mm): Via [GND] auf F.Cu - B.Cu
[holes_co_located]: Drilled holes co-located
    Local override; warning
    @(52.1600 mm, 54.0000 mm): Durchsteckpad 2 [GND] von R_TRS
    @(52.1600 mm, 54.0000 mm): Via [GND] auf F.Cu - B.Cu
[holes_co_located]: Drilled holes co-located
    Local override; warning
    @(52.1600 mm, 62.0000 mm): Durchsteckpad 2 [GND] von R_TXR1
    @(52.1600 mm, 62.0000 mm): Via [GND] auf F.Cu - B.Cu
[holes_co_located]: Drilled holes co-located
    Local override; warning
    @(70.0000 mm, 88.0000 mm): Via [AF_RX] auf F.Cu - B.Cu
    @(70.0000 mm, 88.0000 mm): Durchsteckpad 1 [AF_RX] von C_RX
[holes_co_located]: Drilled holes co-located
    Local override; warning
    @(75.0000 mm, 88.0000 mm): Durchsteckpad 2 [RXA] von C_RX
    @(75.0000 mm, 88.0000 mm): Via [RXA] auf F.Cu - B.Cu
[holes_co_located]: Drilled holes co-located
    Local override; warning
    @(58.0000 mm, 80.0000 mm): Durchsteckpad 1 [TXA] von RV1
    @(58.0000 mm, 80.0000 mm): Via [TXA] auf F.Cu - B.Cu
[holes_co_located]: Drilled holes co-located
    Local override; warning
    @(52.9200 mm, 80.0000 mm): Via [GND] auf F.Cu - B.Cu
    @(52.9200 mm, 80.0000 mm): Durchsteckpad 3 [GND] von RV1
[holes_co_located]: Drilled holes co-located
    Local override; warning
    @(55.4600 mm, 94.0000 mm): Via [CDL] auf F.Cu - B.Cu
    @(55.4600 mm, 94.0000 mm): Durchsteckpad 2 [CDL] von RV_CDL
[holes_co_located]: Drilled holes co-located
    Local override; warning
    @(52.9200 mm, 94.0000 mm): Via [GND] auf F.Cu - B.Cu
    @(52.9200 mm, 94.0000 mm): Durchsteckpad 3 [GND] von RV_CDL
[holes_co_located]: Drilled holes co-located
    Local override; warning
    @(182.0000 mm, 72.9200 mm): Via [AF_RX] auf F.Cu - B.Cu
    @(182.0000 mm, 72.9200 mm): Durchsteckpad 2 [AF_RX] von J_AF
[holes_co_located]: Drilled holes co-located
    Local override; warning
    @(182.0000 mm, 62.7600 mm): Via [GND] auf F.Cu - B.Cu
    @(182.0000 mm, 62.7600 mm): Durchsteckpad 4 [GND] von J_AF
[holes_co_located]: Drilled holes co-located
    Local override; warning
    @(148.0000 mm, 58.0000 mm): Durchsteckpad 1 [GND] von Q1
    @(148.0000 mm, 58.0000 mm): Via [GND] auf F.Cu - B.Cu
[holes_co_located]: Drilled holes co-located
    Local override; warning
    @(178.0000 mm, 28.0000 mm): Via [GND] auf F.Cu - B.Cu
    @(178.0000 mm, 28.0000 mm): Durchsteckpad 1 [GND] von LED_PWR
[holes_co_located]: Drilled holes co-located
    Local override; warning
    @(178.0000 mm, 40.0000 mm): Durchsteckpad 1 [GND] von LED_PTT
    @(178.0000 mm, 40.0000 mm): Via [GND] auf F.Cu - B.Cu
[holes_co_located]: Drilled holes co-located
    Local override; warning
    @(178.0000 mm, 52.0000 mm): Via [GND] auf F.Cu - B.Cu
    @(178.0000 mm, 52.0000 mm): Durchsteckpad 1 [GND] von LED_DCD
[holes_co_located]: Drilled holes co-located
    Local override; warning
    @(178.0000 mm, 64.0000 mm): Via [GND] auf F.Cu - B.Cu
    @(178.0000 mm, 64.0000 mm): Durchsteckpad 1 [GND] von LED_TXRX
[holes_co_located]: Drilled holes co-located
    Local override; warning
    @(160.0000 mm, 40.0000 mm): Via [LED_PTT_N] auf F.Cu - B.Cu
    @(160.0000 mm, 40.0000 mm): Durchsteckpad 1 [LED_PTT_N] von R_LED2
[holes_co_located]: Drilled holes co-located
    Local override; warning
    @(160.0000 mm, 52.0000 mm): Durchsteckpad 1 [LED_DCD_N] von R_LED3
    @(160.0000 mm, 52.0000 mm): Via [LED_DCD_N] auf F.Cu - B.Cu
[holes_co_located]: Drilled holes co-located
    Local override; warning
    @(72.0000 mm, 102.0000 mm): Via [3V3] auf F.Cu - B.Cu
    @(72.0000 mm, 102.0000 mm): Durchsteckpad 1 [3V3] von U_LVL
[holes_co_located]: Drilled holes co-located
    Local override; warning
    @(72.0000 mm, 104.5400 mm): Via [I2C_SDA_3V3] auf F.Cu - B.Cu
    @(72.0000 mm, 104.5400 mm): Durchsteckpad 3 [I2C_SDA_3V3] von U_LVL
[holes_co_located]: Drilled holes co-located
    Local override; warning
    @(72.0000 mm, 107.0800 mm): Durchsteckpad 5 [I2C_SCL_3V3] von U_LVL
    @(72.0000 mm, 107.0800 mm): Via [I2C_SCL_3V3] auf F.Cu - B.Cu
[holes_co_located]: Drilled holes co-located
    Local override; warning
    @(72.0000 mm, 109.6200 mm): Durchsteckpad 7 [GND] von U_LVL
    @(72.0000 mm, 109.6200 mm): Via [GND] auf F.Cu - B.Cu
[holes_co_located]: Drilled holes co-located
    Local override; warning
    @(74.5400 mm, 109.6200 mm): Durchsteckpad 8 [GND] von U_LVL
    @(74.5400 mm, 109.6200 mm): Via [GND] auf F.Cu - B.Cu
[holes_co_located]: Drilled holes co-located
    Local override; warning
    @(100.0000 mm, 102.0000 mm): Durchsteckpad 1 [GND] von J_LCD_I2C
    @(100.0000 mm, 102.0000 mm): Via [GND] auf F.Cu - B.Cu
[holes_co_located]: Drilled holes co-located
    Local override; warning
    @(122.9200 mm, 100.0000 mm): Via [GND] auf F.Cu - B.Cu
    @(122.9200 mm, 100.0000 mm): Durchsteckpad 3 [GND] von RV2
[text_height]: Schrifthöhe außerhalb des zulässigen Bereichs (Einschränkungen aus Platinenkonfiguration zur Bestückungsdruckhöhe min. Breite 0,8000 mm; tatsächlich 0,7000 mm)
    Rule: Einschränkungen aus Platinenkonfiguration zur Bestückungsdruckhöhe; warning
    @(42.0000 mm, 50.0000 mm): Platinen-Text "TRS->GND" auf F.Silkscreen
[text_height]: Schrifthöhe außerhalb des zulässigen Bereichs (Einschränkungen aus Platinenkonfiguration zur Bestückungsdruckhöhe min. Breite 0,8000 mm; tatsächlich 0,7000 mm)
    Rule: Einschränkungen aus Platinenkonfiguration zur Bestückungsdruckhöhe; warning
    @(42.0000 mm, 58.0000 mm): Platinen-Text "TXR1->GND 0R" auf F.Silkscreen
[text_height]: Schrifthöhe außerhalb des zulässigen Bereichs (Einschränkungen aus Platinenkonfiguration zur Bestückungsdruckhöhe min. Breite 0,8000 mm; tatsächlich 0,7000 mm)
    Rule: Einschränkungen aus Platinenkonfiguration zur Bestückungsdruckhöhe; warning
    @(28.0000 mm, 72.0000 mm): Platinen-Text "TXR2->+5V_OR 0R" auf F.Silkscreen
[text_height]: Schrifthöhe außerhalb des zulässigen Bereichs (Einschränkungen aus Platinenkonfiguration zur Bestückungsdruckhöhe min. Breite 0,8000 mm; tatsächlich 0,7000 mm)
    Rule: Einschränkungen aus Platinenkonfiguration zur Bestückungsdruckhöhe; warning
    @(128.0000 mm, 96.0000 mm): Platinen-Text "LCD_VO=RV2 wiper only (NC intentional)" auf F.Silkscreen
[silk_overlap]: Silkscreen clearance
    Rule: Einschränkungen aus Platinenkonfiguration zum Bestückungsdruck; warning
    @(100.0000 mm, 34.0000 mm): Platinen-Text "U1 Pico H socket" auf F.Silkscreen
    @(98.8900 mm, 35.1300 mm): Kreisbogen von U1 auf F.Silkscreen
[silk_overlap]: Silkscreen clearance
    Rule: Einschränkungen aus Platinenkonfiguration zum Bestückungsdruck; warning
    @(100.0000 mm, 34.0000 mm): Platinen-Text "U1 Pico H socket" auf F.Silkscreen
    @(98.8900 mm, 34.5200 mm): Abschnitt von U1 auf F.Silkscreen
[silk_overlap]: Silkscreen clearance
    Rule: Einschränkungen aus Platinenkonfiguration zum Bestückungsdruck; warning
    @(128.0000 mm, 96.0000 mm): Platinen-Text "LCD_VO=RV2 wiper only (NC intentional)" auf F.Silkscreen
    @(125.4600 mm, 96.3400 mm): Referenzfeld von RV2
[silk_overlap]: Silkscreen clearance
    Rule: Einschränkungen aus Platinenkonfiguration zum Bestückungsdruck; warning
    @(49.3800 mm, 23.2700 mm): Abschnitt von J_USB_PICO auf F.Silkscreen
    @(48.0000 mm, 28.0000 mm): Platinen-Text "to Pico Micro-USB cable" auf F.Silkscreen
[silk_overlap]: Silkscreen clearance
    Rule: Einschränkungen aus Platinenkonfiguration zum Bestückungsdruck; warning
    @(50.5000 mm, 31.5000 mm): Referenzfeld von C_Y2
    @(46.6200 mm, 31.0000 mm): Abschnitt von J_USB_PICO auf F.Silkscreen
[silk_overlap]: Silkscreen clearance
    Rule: Einschränkungen aus Platinenkonfiguration zum Bestückungsdruck; warning
    @(50.5000 mm, 31.5000 mm): Referenzfeld von C_Y2
    @(49.3800 mm, 23.2700 mm): Abschnitt von J_USB_PICO auf F.Silkscreen
[silk_overlap]: Silkscreen clearance
    Rule: Einschränkungen aus Platinenkonfiguration zum Bestückungsdruck; warning
    @(69.4000 mm, 7.0000 mm): Abschnitt von J_DC auf F.Silkscreen
    @(68.2500 mm, 3.5500 mm): Referenzfeld von J_DC
[silk_overlap]: Silkscreen clearance
    Rule: Einschränkungen aus Platinenkonfiguration zum Bestückungsdruck; warning
    @(46.6200 mm, 23.2700 mm): Abschnitt von J_USB_PICO auf F.Silkscreen
    @(48.0000 mm, 28.0000 mm): Platinen-Text "to Pico Micro-USB cable" auf F.Silkscreen
[silk_overlap]: Silkscreen clearance
    Rule: Einschränkungen aus Platinenkonfiguration zum Bestückungsdruck; warning
    @(33.0800 mm, 65.6300 mm): Referenzfeld von R_TXR2
    @(20.6700 mm, 50.6100 mm): Rechteck von SKT_MODEM auf F.Silkscreen
[silk_overlap]: Silkscreen clearance
    Rule: Einschränkungen aus Platinenkonfiguration zum Bestückungsdruck; warning
    @(29.8100 mm, 66.6300 mm): Rechteck von R_TXR2 auf F.Silkscreen
    @(20.6700 mm, 50.6100 mm): Rechteck von SKT_MODEM auf F.Silkscreen
[silk_overlap]: Silkscreen clearance
    Rule: Einschränkungen aus Platinenkonfiguration zum Bestückungsdruck; warning
    @(50.5850 mm, 96.5300 mm): Abschnitt von RV_CDL auf F.Silkscreen
    @(60.0000 mm, 96.0000 mm): Platinen-Text "U_LVL BSS138 LV=3V3 HV=+5V_OR" auf F.Silkscreen
[silk_overlap]: Silkscreen clearance
    Rule: Einschränkungen aus Platinenkonfiguration zum Bestückungsdruck; warning
    @(60.3350 mm, 96.5300 mm): Abschnitt von RV_CDL auf F.Silkscreen
    @(60.0000 mm, 96.0000 mm): Platinen-Text "U_LVL BSS138 LV=3V3 HV=+5V_OR" auf F.Silkscreen
[silk_overlap]: Silkscreen clearance
    Rule: Einschränkungen aus Platinenkonfiguration zum Bestückungsdruck; warning
    @(60.3350 mm, 91.4800 mm): Abschnitt von RV_CDL auf F.Silkscreen
    @(60.0000 mm, 96.0000 mm): Platinen-Text "U_LVL BSS138 LV=3V3 HV=+5V_OR" auf F.Silkscreen
[silk_overlap]: Silkscreen clearance
    Rule: Einschränkungen aus Platinenkonfiguration zum Bestückungsdruck; warning
    @(78.6000 mm, -1.8000 mm): Abschnitt von J_DC auf F.Silkscreen
    @(95.0000 mm, 2.5000 mm): Platinen-Text "T-Modem v0.25 GPLv3 AS-IS" auf F.Silkscreen
[silk_overlap]: Silkscreen clearance
    Rule: Einschränkungen aus Platinenkonfiguration zum Bestückungsdruck; warning
    @(178.8000 mm, 70.3800 mm): Referenzfeld von J_AF
    @(179.8900 mm, 81.6500 mm): Rechteck von J_AF auf F.Silkscreen
[silk_overlap]: Silkscreen clearance
    Rule: Einschränkungen aus Platinenkonfiguration zum Bestückungsdruck; warning
    @(182.0000 mm, 82.0000 mm): Platinen-Text "AF_RX" auf F.Silkscreen
    @(179.8900 mm, 81.6500 mm): Rechteck von J_AF auf F.Silkscreen
[silk_overlap]: Silkscreen clearance
    Rule: Einschränkungen aus Platinenkonfiguration zum Bestückungsdruck; warning
    @(178.0000 mm, 62.7300 mm): Kreisbogen von LED_TXRX auf F.Silkscreen
    @(179.8900 mm, 81.6500 mm): Rechteck von J_AF auf F.Silkscreen
[silk_overlap]: Silkscreen clearance
    Rule: Einschränkungen aus Platinenkonfiguration zum Bestückungsdruck; warning
    @(103.6521 mm, 34.5200 mm): Abschnitt von U1 auf F.Silkscreen
    @(100.0000 mm, 34.0000 mm): Platinen-Text "U1 Pico H socket" auf F.Silkscreen
[silk_overlap]: Silkscreen clearance
    Rule: Einschränkungen aus Platinenkonfiguration zum Bestückungsdruck; warning
    @(104.7800 mm, 33.2200 mm): Abschnitt von U1 auf F.Silkscreen
    @(100.0000 mm, 34.0000 mm): Platinen-Text "U1 Pico H socket" auf F.Silkscreen
[silk_overlap]: Silkscreen clearance
    Rule: Einschränkungen aus Platinenkonfiguration zum Bestückungsdruck; warning
    @(104.7800 mm, 34.0400 mm): Abschnitt von U1 auf F.Silkscreen
    @(100.0000 mm, 34.0000 mm): Platinen-Text "U1 Pico H socket" auf F.Silkscreen
[silk_overlap]: Silkscreen clearance
    Rule: Einschränkungen aus Platinenkonfiguration zum Bestückungsdruck; warning
    @(100.0000 mm, 34.0000 mm): Platinen-Text "U1 Pico H socket" auf F.Silkscreen
    @(104.9900 mm, 34.0400 mm): Abschnitt von U1 auf F.Silkscreen
[silk_overlap]: Silkscreen clearance
    Rule: Einschränkungen aus Platinenkonfiguration zum Bestückungsdruck; warning
    @(104.6550 mm, 34.5200 mm): Abschnitt von U1 auf F.Silkscreen
    @(100.0000 mm, 34.0000 mm): Platinen-Text "U1 Pico H socket" auf F.Silkscreen
[silk_overlap]: Silkscreen clearance
    Rule: Einschränkungen aus Platinenkonfiguration zum Bestückungsdruck; warning
    @(100.0000 mm, 34.0000 mm): Platinen-Text "U1 Pico H socket" auf F.Silkscreen
    @(101.3800 mm, 34.5200 mm): Abschnitt von U1 auf F.Silkscreen
[silk_overlap]: Silkscreen clearance
    Rule: Einschränkungen aus Platinenkonfiguration zum Bestückungsdruck; warning
    @(165.0800 mm, 25.6300 mm): Referenzfeld von R_LED1
    @(160.3600 mm, 22.5300 mm): Rechteck von D_OR2 auf F.Silkscreen
[silk_overlap]: Silkscreen clearance
    Rule: Einschränkungen aus Platinenkonfiguration zum Bestückungsdruck; warning
    @(178.0000 mm, 26.7300 mm): Kreisbogen von LED_PWR auf F.Silkscreen
    @(175.0400 mm, 26.7300 mm): Referenzfeld von LED_PWR
[silk_overlap]: Silkscreen clearance
    Rule: Einschränkungen aus Platinenkonfiguration zum Bestückungsdruck; warning
    @(175.0400 mm, 26.7300 mm): Referenzfeld von LED_PWR
    @(178.0000 mm, 26.7300 mm): Kreisbogen von LED_PWR auf F.Silkscreen
[silk_overlap]: Silkscreen clearance
    Rule: Einschränkungen aus Platinenkonfiguration zum Bestückungsdruck; warning
    @(175.0400 mm, 38.7300 mm): Referenzfeld von LED_PTT
    @(178.0000 mm, 38.7300 mm): Kreisbogen von LED_PTT auf F.Silkscreen
[silk_overlap]: Silkscreen clearance
    Rule: Einschränkungen aus Platinenkonfiguration zum Bestückungsdruck; warning
    @(175.0400 mm, 38.7300 mm): Referenzfeld von LED_PTT
    @(178.0000 mm, 38.7300 mm): Kreisbogen von LED_PTT auf F.Silkscreen
[silk_overlap]: Silkscreen clearance
    Rule: Einschränkungen aus Platinenkonfiguration zum Bestückungsdruck; warning
    @(175.0400 mm, 50.7300 mm): Referenzfeld von LED_DCD
    @(178.0000 mm, 50.7300 mm): Kreisbogen von LED_DCD auf F.Silkscreen
[silk_overlap]: Silkscreen clearance
    Rule: Einschränkungen aus Platinenkonfiguration zum Bestückungsdruck; warning
    @(175.0400 mm, 50.7300 mm): Referenzfeld von LED_DCD
    @(178.0000 mm, 50.7300 mm): Kreisbogen von LED_DCD auf F.Silkscreen
[silk_overlap]: Silkscreen clearance
    Rule: Einschränkungen aus Platinenkonfiguration zum Bestückungsdruck; warning
    @(175.0400 mm, 62.7300 mm): Referenzfeld von LED_TXRX
    @(178.0000 mm, 62.7300 mm): Kreisbogen von LED_TXRX auf F.Silkscreen
[silk_overlap]: Silkscreen clearance
    Rule: Einschränkungen aus Platinenkonfiguration zum Bestückungsdruck; warning
    @(175.0400 mm, 62.7300 mm): Referenzfeld von LED_TXRX
    @(178.0000 mm, 62.7300 mm): Kreisbogen von LED_TXRX auf F.Silkscreen
[silk_over_copper]: Silkscreen clipped by solder mask
    Local override; warning
    @(48.0000 mm, 28.0000 mm): Platinen-Text "to Pico Micro-USB cable" auf F.Silkscreen
    @(48.0000 mm, 27.0800 mm): Durchsteckpad 3 [USB_DP] von J_USB_PICO
[silk_over_copper]: Silkscreen clipped by solder mask
    Local override; warning
    @(29.0400 mm, 68.0000 mm): Abschnitt von R_TXR2 auf F.Silkscreen
    @(29.6200 mm, 67.2400 mm): Durchsteckpad 10 [CDL] von SKT_MODEM
[silk_over_copper]: Silkscreen clipped by solder mask
    Local override; warning
    @(29.8100 mm, 66.6300 mm): Rechteck von R_TXR2 auf F.Silkscreen
    @(29.6200 mm, 67.2400 mm): Durchsteckpad 10 [CDL] von SKT_MODEM
[silk_over_copper]: Silkscreen clipped by solder mask
    Local override; warning
    @(29.8100 mm, 66.6300 mm): Rechteck von R_TXR2 auf F.Silkscreen
    @(29.6200 mm, 69.7800 mm): Durchsteckpad 9 [GND] von SKT_MODEM
[silk_over_copper]: Silkscreen clipped by solder mask
    Local override; warning
    @(28.4600 mm, 71.1100 mm): Abschnitt von SKT_MODEM auf F.Silkscreen
    @(28.0000 mm, 68.0000 mm): Durchsteckpad 1 [TXR2_N] von R_TXR2
[silk_over_copper]: Silkscreen clipped by solder mask
    Local override; warning
    @(28.0000 mm, 76.0000 mm): Platinen-Text "confirm datasheet" auf F.Silkscreen
    @(22.0000 mm, 76.0000 mm): Durchsteckpad 1 [+5V_OR] von C_BYP1
[silk_over_copper]: Silkscreen clipped by solder mask
    Local override; warning
    @(28.0000 mm, 76.0000 mm): Platinen-Text "confirm datasheet" auf F.Silkscreen
    @(27.0000 mm, 76.0000 mm): Durchsteckpad 2 [GND] von C_BYP1
[silk_over_copper]: Silkscreen clipped by solder mask
    Local override; warning
    @(182.0000 mm, 66.0000 mm): Platinen-Text "GND" auf F.Silkscreen
    @(182.0000 mm, 67.8400 mm): Durchsteckpad 3 [PTT_OC] von J_AF
[silk_over_copper]: Silkscreen clipped by solder mask
    Local override; warning
    @(182.0000 mm, 74.0000 mm): Platinen-Text "PTT" auf F.Silkscreen
    @(182.0000 mm, 72.9200 mm): Durchsteckpad 2 [AF_RX] von J_AF
[silk_over_copper]: Silkscreen clipped by solder mask
    Local override; warning
    @(175.0400 mm, 62.7300 mm): Referenzfeld von LED_TXRX
    @(178.0000 mm, 64.0000 mm): Durchsteckpad 1 [GND] von LED_TXRX
[silk_over_copper]: Silkscreen clipped by solder mask
    Local override; warning
    @(175.0400 mm, 62.7300 mm): Referenzfeld von LED_TXRX
    @(178.0000 mm, 61.4600 mm): Durchsteckpad 2 [LED_TXRX_A] von LED_TXRX
[silk_over_copper]: Silkscreen clipped by solder mask
    Local override; warning
    @(175.0400 mm, 26.7300 mm): Referenzfeld von LED_PWR
    @(178.0000 mm, 28.0000 mm): Durchsteckpad 1 [GND] von LED_PWR
[silk_over_copper]: Silkscreen clipped by solder mask
    Local override; warning
    @(175.0400 mm, 26.7300 mm): Referenzfeld von LED_PWR
    @(178.0000 mm, 25.4600 mm): Durchsteckpad 2 [LED_PWR_A] von LED_PWR
[silk_over_copper]: Silkscreen clipped by solder mask
    Local override; warning
    @(175.0400 mm, 38.7300 mm): Referenzfeld von LED_PTT
    @(178.0000 mm, 37.4600 mm): Durchsteckpad 2 [LED_PTT_A] von LED_PTT
[silk_over_copper]: Silkscreen clipped by solder mask
    Local override; warning
    @(175.0400 mm, 38.7300 mm): Referenzfeld von LED_PTT
    @(178.0000 mm, 40.0000 mm): Durchsteckpad 1 [GND] von LED_PTT
[silk_over_copper]: Silkscreen clipped by solder mask
    Local override; warning
    @(175.0400 mm, 50.7300 mm): Referenzfeld von LED_DCD
    @(178.0000 mm, 52.0000 mm): Durchsteckpad 1 [GND] von LED_DCD
[silk_over_copper]: Silkscreen clipped by solder mask
    Local override; warning
    @(175.0400 mm, 50.7300 mm): Referenzfeld von LED_DCD
    @(178.0000 mm, 49.4600 mm): Durchsteckpad 2 [LED_DCD_A] von LED_DCD

** Found 6 unconnected pads **
[unconnected_items]: Missing connection between items
    Local override; error
    @(52.1600 mm, 54.0000 mm): Via [GND] auf F.Cu - B.Cu
    @(53.0000 mm, 34.0000 mm): Durchsteckpad 2 [GND] von C_Y2
[unconnected_items]: Missing connection between items
    Local override; error
    @(52.1600 mm, 62.0000 mm): Via [GND] auf F.Cu - B.Cu
    @(52.1600 mm, 54.0000 mm): Via [GND] auf F.Cu - B.Cu
[unconnected_items]: Missing connection between items
    Local override; error
    @(52.1600 mm, 62.0000 mm): Via [GND] auf F.Cu - B.Cu
    @(52.9200 mm, 80.0000 mm): Durchsteckpad 3 [GND] von RV1
[unconnected_items]: Missing connection between items
    Local override; error
    @(53.0000 mm, 34.0000 mm): Durchsteckpad 2 [GND] von C_Y2
    @(48.0000 mm, 29.6200 mm): Via [GND] auf F.Cu - B.Cu
[unconnected_items]: Missing connection between items
    Local override; error
    @(1.0000 mm, 1.0000 mm): Zone [GND] auf B.Cu, Priorität 1
    @(1.0000 mm, 1.0000 mm): Zone [GND] auf B.Cu, Priorität 1
[unconnected_items]: Missing connection between items
    Local override; error
    @(100.0000 mm, 41.0800 mm): Durchsteckpad 3 [GND] von U1
    @(87.0000 mm, 30.0000 mm): Via [GND] auf F.Cu - B.Cu

** Found 0 Footprint errors **

** Ignored checks **
    - Footprint has no courtyard defined
    - Track endpoint not centered on via
    - Tuning profile track geometries
    - Footprint doesn't match symbol's footprint filters
    - Footprint component type doesn't match footprint pads

** End of Report **

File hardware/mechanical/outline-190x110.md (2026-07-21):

# Board outline — 190 × 110 mm

**T-Modem v0.25** · hand-solderable TH reference · §0.26 larger OK

| Item | Value |
|---|---|
| Size | 190 × 110 mm |
| Thickness | 1.6 mm |
| Mounts | M3 ×4 at (6,6), (184,6), (6,104), (184,104) |
| Supersedes | `outline-160x100.md` |

Edge.Cuts rectangle in `hardware/kicad/t-modem/t-modem.kicad_pcb`.

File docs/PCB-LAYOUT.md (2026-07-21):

# PCB layout policy — safe · stable · performant

**Status:** settled 2026-07-21 · **complete PCB delivered** (v0.25)  
**Baseline:** tag **`v0.25`** · outline **190 × 110 mm** (larger OK for hand soldering)  
**AS-IS** · **standard reference only** · GPLv3

Policy: complete PCB; prefer larger over fiddly; finish DRC before fab.  
**Always:** **Safe · Stable · Performant · KISS**.

---

## Rule

Implement the **complete** T-Modem PCB for **safe**, **stable**, and **performant** operation under **KISS**. Prefer a **somewhat larger** board over a **too small / fiddly** layout.

| Pillar | Requirement |
|---|---|
| **Safe** | Clearances, fuse/OR path, readable polarity silk, serviceable connectors |
| **Stable** | Solid GND pour (B.Cu), short analog/crystal paths, DIP sockets and headers |
| **Performant** | USB Path B discipline; AF/PTT away from USB/digital; adequate power copper |
| **KISS** | One layout path; no parallel mystery boards |
| **Larger > fiddly** | **190 × 110 mm** so hand soldering (TH) stays comfortable |

## Delivered (v0.25)

| Item | Location |
|---|---|
| KiCad 10 project | `hardware/kicad/t-modem/` |
| Regenerator (no pcbnew) | `hardware/kicad/t-modem/scripts/generate_board.py` |
| Gerber export notes + sample | `hardware/fab/` |
| Outline | `hardware/mechanical/outline-190x110.md` (earlier 160×100 / 100×80 drafts superseded) |

**Routing honesty (2026-07-21):** `generate_board.py` collision-aware manhattan + A* + B.Cu edge fallback; **no `ignore_used` shorts**. GND = **B.Cu pour**; **+5V_OR** = **F.Cu pour** (tracks skipped). **Intentional:** `LCD_VO` = RV2 wiper only (no LCD module pin); **BOOTSEL** = SW1 ↔ TP_BOOTSEL only — **flying lead** to Pico BOOTSEL test pad. Clear remaining DRC before fab.

## vs hardware baseline

Allowed: finish KiCad, enlarge outline for assembly/safety, layout fixes.  
Settled (do not swap for taste): MCU / modem PHY / display **class** and connector **class** (USB-A Path B, optional 12 V barrel, I²C LCD default).

Companion: [PCB-ASSEMBLY.md](PCB-ASSEMBLY.md) · [HARDWARE-BASELINE.md](HARDWARE-BASELINE.md) · [SCHEMATIC.md](SCHEMATIC.md).

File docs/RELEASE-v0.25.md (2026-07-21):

# Release v0.25 — hardware-only standard reference

**Version:** 0.25  
**Git tag:** `v0.25`  
**Date:** 2026-07-20 · **docs refresh:** 2026-07-21  
**License:** GNU GPLv3 · **AS-IS** — no support, no warranty  
**Scope:** **standard reference only**

**Verification:** [v0.25-VERIFICATION.md](v0.25-VERIFICATION.md) · **Baseline:** [HARDWARE-BASELINE.md](HARDWARE-BASELINE.md)

**Operator path:** build this hardware **as-is** toward **v1.0**; firmware/software **after** the build. No redesign for preference.

---

## What this release is

A **hardware reference** package (solderable / finish-in-KiCad):

- Preferred commodity parts (BOM) with honest **TBD** where MPN not yet picked from stock
- Electrical intent: **USB and/or 12 V** · USB Type-A device · green LCD · Pico UF2 · TCM3105-class AFSK IF
- Rectangle PCB outline **190 × 110 mm** + connector placement + assembly notes
- KiCad project with complete TH board (DRC cleanup before fab order)

## What this release is not

| Not included | Note |
|---|---|
| Firmware | [../firmware/README.md](../firmware/README.md) placeholder |
| Host software / MAX25 plugin | [../software/README.md](../software/README.md) placeholder |
| Radio mic pinouts | Never invented — screw terminals labeled by function only |
| BayCom / SER12 / PC-COM | Out of product scope |
| Custom / commercial SKU lines | Not T-Modem |
| Verified fab Gerbers | Operator clears DRC before order |

---

## Deliverable map

| Artifact | Path |
|---|---|
| VERSION | [`../VERSION`](../VERSION) → `0.25` |
| Verification | [v0.25-VERIFICATION.md](v0.25-VERIFICATION.md) |
| Baseline | [HARDWARE-BASELINE.md](HARDWARE-BASELINE.md) |
| BOM (human) | [BOM.md](BOM.md) |
| BOM (CSV) | [`../hardware/bom/BOM.csv`](../hardware/bom/BOM.csv) |
| Schematic / netlist | [SCHEMATIC.md](SCHEMATIC.md) |
| PCB / assembly | [PCB-ASSEMBLY.md](PCB-ASSEMBLY.md) · [PCB-LAYOUT.md](PCB-LAYOUT.md) |
| KiCad project | [`../hardware/kicad/t-modem/`](../hardware/kicad/t-modem/) |
| Mechanical outline | [`../hardware/mechanical/outline-190x110.md`](../hardware/mechanical/outline-190x110.md) |
| Fab notes | [`../hardware/fab/`](../hardware/fab/) |

---

## Electrical readiness (HW now / FW later)

| Subsystem | v0.25 hardware | Firmware later |
|---|---|---|
| USB → `+5V_OR` (USB-only OK) | Designed | — |
| Optional 12 V barrel → buck → `+5V_OR` | On reference, not required | — |
| USB Type-A receptacle (device) | Path B to Pico | CDC/ACM + KISS |
| UF2 / BOOTSEL field flash | BOOTSEL + USB path | Application image |
| 16×2 green LCD (HD44780) | I²C default (+ U_LVL) | UI / status |
| TCM3105-class AFSK 1200 + AF/PTT | In netlist | Drive TXD/RXD/CDT/PTT |
| AFSK 2400 | MCU pins reserved | Soft-AFSK / DSP |
| Radio connector map | Function labels only | — |

---

## Sources

| Claim | Rights-granting source | Local copy |
|---|---|---|
| GPLv3 | https://www.gnu.org/licenses/gpl-3.0.html | `../LICENSE` |
| RP2040 / Pico | https://datasheets.raspberrypi.com/rp2040/rp2040-datasheet.pdf · https://datasheets.raspberrypi.com/pico/pico-datasheet.pdf | — |
| TCM3105 | https://www.qsl.net/o/on7pc/datasheet/ic/TCM3105.pdf | — |
| HD44780U | https://cdn.sparkfun.com/assets/9/5/f/7/b/HD44780.pdf | — |

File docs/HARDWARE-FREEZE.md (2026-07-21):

# Hardware freeze — redirect

**Status:** obsolete filename — use **[HARDWARE-BASELINE.md](HARDWARE-BASELINE.md)**

Same policy (v0.25 settled → build to v1.0; software after). The word *freeze* was dropped in favour of **baseline** / **settled**.

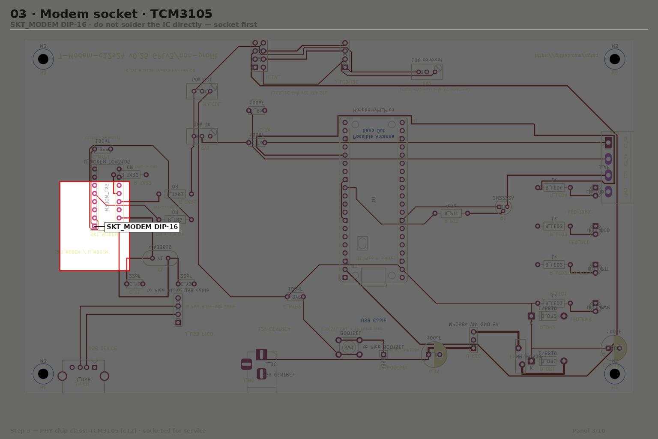
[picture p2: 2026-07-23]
docs/images/explode/t-modem-explode-03-modem-socket.png

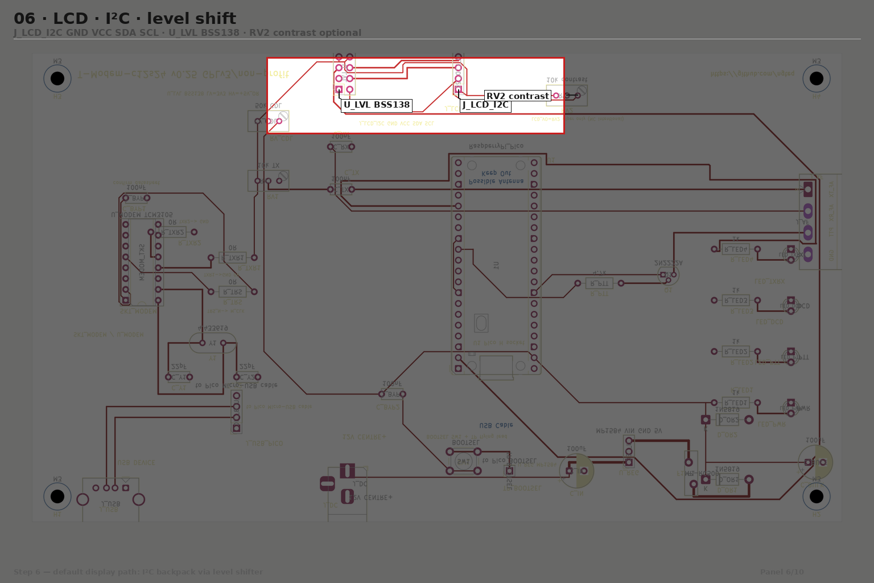
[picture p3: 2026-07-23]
docs/images/explode/t-modem-explode-06-lcd-i2c.png

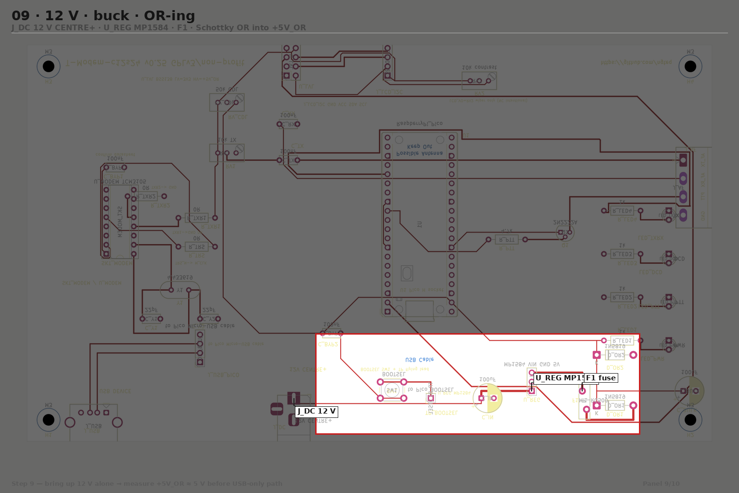
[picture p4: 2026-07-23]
docs/images/explode/t-modem-explode-09-power-dc.png

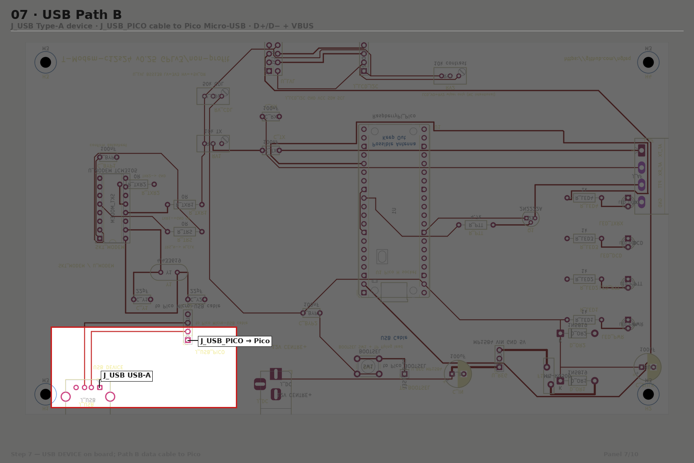
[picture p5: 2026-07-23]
docs/images/explode/t-modem-explode-07-usb.png

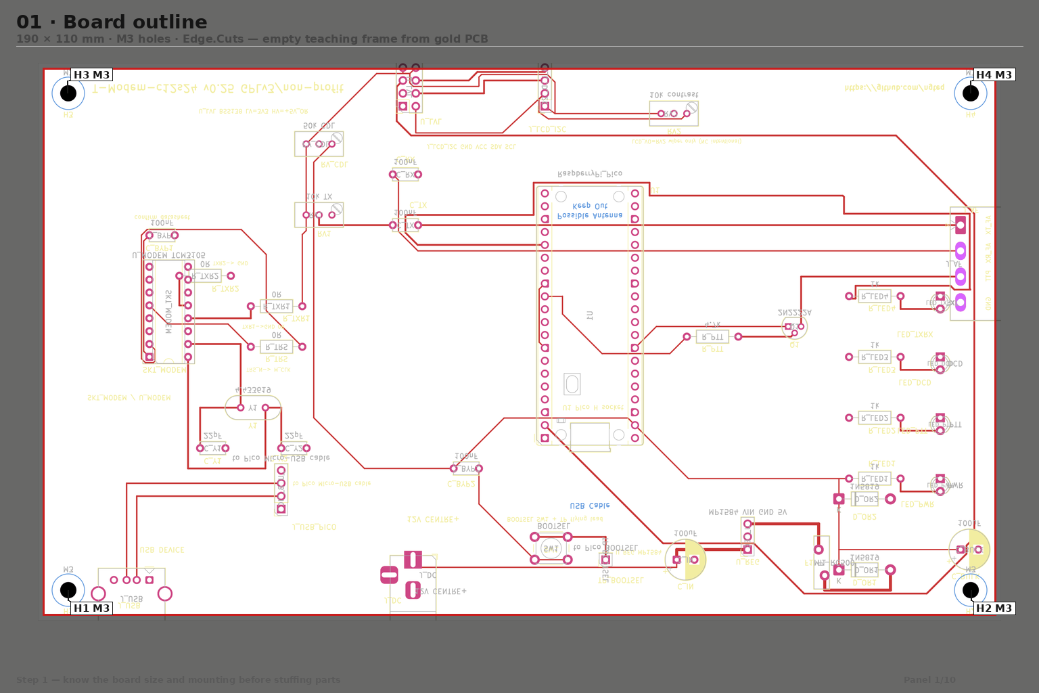
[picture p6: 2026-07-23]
docs/images/explode/t-modem-explode-01-board-outline.png

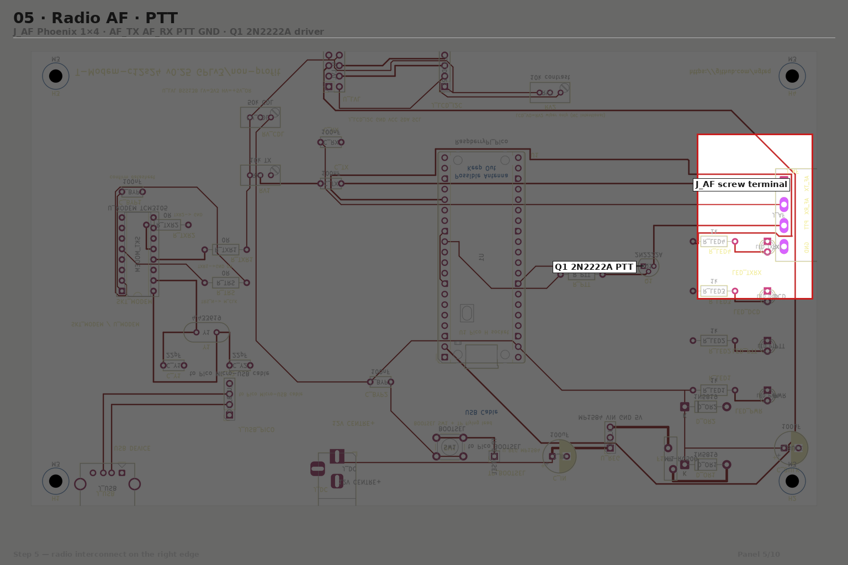
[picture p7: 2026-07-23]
docs/images/explode/t-modem-explode-05-radio-af.png

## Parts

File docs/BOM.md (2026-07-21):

# Bill of materials — v0.25 (hardware reference)

**Status:** assemble-ready **candidates** — prefer in-production commodity; mark **TBD** where MPN not yet picked from stock  
**AS-IS:** no support, no warranty · **standard reference only**  
**Hobby-friendly:** **sockets + through-hole** — hand soldering for anyone who can solder reasonably well  
**Budget:** prefer **cheap commodity** modules/sockets (see [ORDERING-BUDGET.md](ORDERING-BUDGET.md)) — best value, not boutique parts  
**CSV:** [`../hardware/bom/BOM.csv`](../hardware/bom/BOM.csv)

Do **not** invent radio mic pinouts. BayCom/SER12 parts are forbidden.

---

## Hobby-friendly mounting (required for reference)

| Ref | Qty | Description | Preferred candidate | Role | Status |
|-----|-----|---|---|---|---|
| SKT_MODEM | 1 | **16-pin DIP socket** 0.3″ (7.62 mm) | **Cheap generic** DIP socket OK (turned-pin nicer but not required) | Holds U_MODEM — **do not solder IC pins directly** | **Preferred** |
| HDR_PICO_F | 2 | **Female** 1×20 header 2.54 mm | Generic strip / break-to-length | Socket for Pico H | **Preferred** |
| HDR_LCD_F | 1 | **Female** 1×16 (or dual-row per module) 2.54 mm | Generic | Socket / header for LCD | **Preferred** |
| HDR_REG | 1 | Header for buck module | 2.54 mm male pins on module | Plug-in **cheap** 12 V→5 V module | Candidate |

Default passives: **0.25 W through-hole**. SMD 0805 only as optional alternate, not the hobby default.

---

## Preferred MCU path (settled for v0.25 reference)

| Ref | Qty | Description | Preferred candidate | Role | Status |
|-----|-----|---|---|---|---|
| U1 | 1 | MCU module, native USB device, UF2 field flash | **Raspberry Pi Pico H** (RP2040, **headers fitted**) — plug into HDR_PICO_F | Firmware host · USB KISS later · 2400 DSP later | **Preferred** — [Pico datasheet](https://datasheets.raspberrypi.com/pico/pico-datasheet.pdf) · [RP2040](https://datasheets.raspberrypi.com/rp2040/rp2040-datasheet.pdf) |
| SW1 | 1 | Momentary N.O. **TH** | DigiKey-class 6×6 mm tactile (Omron B3F / TE — **MPN TBD** in-stock) | BOOTSEL → GND | Candidate |
| — | — | Alt MCU (not default) | ESP32-S3 module native USB on headers | Only if Pico unavailable | Optional alt |

**Field flash:** hold BOOTSEL, plug USB into PC → UF2 mass-storage (ROM). No separate programmer for normal updates.

---

## Modem PHY (required for “modem” milestone)

| Ref | Qty | Description | Preferred candidate | Role | Status |
|-----|-----|---|---|---|---|
| U_MODEM | 1 | Bell-202 FSK modem IC **DIP-16** | **TCM3105** DIP-16 (or MX614P-class) — insert into **SKT_MODEM** | AFSK **1200** TXA/RXA · RXD/TXD/CDT to Pico | **Preferred class** — [datasheet mirror](https://www.qsl.net/o/on7pc/datasheet/ic/TCM3105.pdf) · longevity: often NOS — verify stock |
| Y1 | 1 | Crystal | **4.4336 MHz** class (confirm vs datasheet) | TCM3105 OSC | Candidate |
| — | 0/1 | Alt if TCM3105 unobtainable | **MX614**-class Bell-202 modem | Same net roles | Optional |
| — | — | 2400 baud | Pico DSP / soft-AFSK (firmware later) | Not TCM3105 headline | TBD FW |

**Longevity (honest):** TCM3105 is **legacy / often NOS**. Prefer active DigiKey/Mouser qty when picking MPN; if none, use MX614-class or document soft-AFSK-only revision. **Not** BayCom SER12 charge-pump.

Netlist: [SCHEMATIC.md](SCHEMATIC.md).

---

## Display (preferred)

| Ref | Qty | Description | Preferred candidate | Status |
|-----|-----|---|---|---|
| DSP1 | 1 | 16×2 HD44780-compatible character LCD, **green LED backlight** | Commodity **16×2 green** (Newhaven / Displaytech / Adafruit-class). Prefer named OEM on DigiKey/Mouser — exact glass MPN = **TBD** after stock pick | **Preferred class** |
| U2 | 0/1 | Optional PCF8574 I²C backpack (often **5 V**) | Common backpack modules | Optional |
| U_LVL | 0/1 | 4-ch bidirectional BSS138 / I²C level shifter (~15×13 mm, headers) | **Operator-approved OK** — **LV=3.3 V** (Pico) · **HV=5 V** (LCD I²C) · **GND** common; required with 5 V backpack; **not** TFT | **Preferred** (I²C path) |
| RV2 | 1 | 10 kΩ trimmer | Bourns 3296 / carbon 10k TH — **MPN TBD** | Contrast |

Controller: Hitachi **HD44780U** — [PDF](https://cdn.sparkfun.com/assets/9/5/f/7/b/HD44780.pdf).

TFT (ST7735/ILI9341) = optional alt only; longevity weaker — not default.

---

## USB and power

| Ref | Qty | Description | Preferred candidate | Status |
|-----|-----|---|---|---|
| J_USB | 1 | USB **Type-A receptacle**, through-hole, USB 2.0 FS | DigiKey [USB connectors](https://www.digikey.com/en/products/filter/usb-dvi-hdmi-connectors/308) — Amphenol / TE / Molex Type-A TH — **pick one in-stock MPN at order** | Class settled · MPN **TBD** at order |
| J_DC | 1 | DC barrel **5.5×2.1 mm**, centre-**positive** (optional path) | DigiKey [barrel](https://www.digikey.com/en/products/filter/barrel-power-connectors/439) — CUI **PJ-002A** class | Size settled; not required for USB-only |
| U_REG | 1 | **12 V → 5 V**, ≥500 mA | Prefer **buck** (MP1584EN class) or AMS1117-5.0 (watch heat) | Candidate |
| D_OR1, D_OR2 | 2 | Schottky ≥1 A | **1N5819** / SS14 | OR USB ↔ 5 V; no host backfeed |
| C_BULK / C_IN | 1+1 | 100 µF electrolytics | Commodity | Bulk |
| C_BYP* | 8+ | 100 nF | 0805 or TH | Decoupling |
| F1 | 1 | PTC ~500 mA hold | DigiKey PTC class | Fault limit |
| — | 1 | Wall wart **12 V** centre-positive 5.5×2.1 ≥0.5 A | Commodity | Not on PCB |

Silk: **12 V CENTRE +** · **USB DEVICE**.

---

## Analog IF / indicators

| Ref | Qty | Description | Preferred candidate | Status |
|-----|-----|---|---|---|
| J_AF | 1 | 4-pin screw 5.08 mm | Phoenix / Wurth / generic — **MPN TBD** | `AF_TX` · `AF_RX` · `PTT` · `GND` only |
| Q1 | 1 | NPN OC PTT | **2N2222A** / **BC547** | Open-collector |
| R_PTT | 1 | 4.7 kΩ | Commodity | Base drive |
| RV1 | 1 | 10 kΩ trimmer | Commodity | TX AF level |
| C_AC* | 2 | 100 nF | Commodity | AF AC couple |
| R_PAD* | 2–4 | 100 Ω … 10 kΩ | Commodity | TX pad / bias |
| D_PROT | 2 | 1N4148 | Commodity | Clamp |
| LED1–4 | 4 | 3 mm LED | Green preferred for PWR | PWR, PTT, DCD, TX/RX |
| R_LED* | 4 | 330 Ω–1 kΩ | Commodity | LED series |

---

## Explicitly out of BOM

| Forbidden | Reason |
|---|---|
| SER12 DTR/RTS/TXD charge-pump as PHY | BayCom/PC-COM — out of scope |
| Programmer-only flash as sole update | Violates USB field-flash Eckpunkt |
| Invented radio mic adapters as “supported” | No verified pinouts |

---

## Sources

| Claim | Rights-granting source | Local copy |
|---|---|---|
| Pico / RP2040 | https://datasheets.raspberrypi.com/pico/pico-datasheet.pdf · https://datasheets.raspberrypi.com/rp2040/rp2040-datasheet.pdf | — |
| TCM3105 | https://www.qsl.net/o/on7pc/datasheet/ic/TCM3105.pdf | — |
| HD44780U | https://cdn.sparkfun.com/assets/9/5/f/7/b/HD44780.pdf | — |
| DigiKey USB / barrel classes | https://www.digikey.com/en/products/filter/usb-dvi-hdmi-connectors/308 · https://www.digikey.com/en/products/filter/barrel-power-connectors/439 | — |
| GPLv3 | https://www.gnu.org/licenses/gpl-3.0.html | `../LICENSE` |

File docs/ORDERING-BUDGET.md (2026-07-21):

# Ordering — budget / hobby value (v0.25)

**Goal:** **best value for money** — socketed, through-hole, hand-solderable by anyone who can solder reasonably well.  
**AS-IS:** no support, no warranty · **standard reference only**  
**Not a price quote:** check live shop prices; prefer in-stock commodity.

Companion: [BOM.md](BOM.md) · [`../hardware/bom/BOM.csv`](../hardware/bom/BOM.csv)

---

## Sourcing rules (cheap but sane)

| Do | Don't |
|----|---|
| Generic **16-pin DIP socket** + insert modem IC | Solder TCM3105/MX614 pins straight into the board |
| **Pico H** or bare Pico + cheap male pins into **female** 2.54 mm sockets | Hand-solder RP2040 BGA/QFN |
| Commodity **16×2 green HD44780** LCD module (many €-range clones with pin header) | Expensive industrial TFT as default |
| **BSS138-class 4-ch I²C level shifter** when using a **5 V** LCD1602 I²C backpack on Pico **3.3 V** | Direct 5 V I²C to Pico GPIO; TFT-specific shifter kits |
| Pre-made **12 V→5 V buck module** (MP1584 / LM2596 class) on pin headers | Designing a discrete SOIC buck from scratch for first build |
| TH resistor/LED/diode assortments | Fine-pitch 0402 as hobby default |
| USB-A **through-hole** receptacle + 5.5×2.1 barrel from hobby catalogues | Exotic connectors |

Shops (examples, not exclusive): Reichelt, Conrad, DigiKey/Mouser value lines, reputable Pico distributors. Verify counterfeit risk on NOS modem ICs (TCM3105).

---

## Suggested buy list (classes)

| # | Item | Qty | Cheap class | Socket / note |
|---|---|-----|---|---|
| 1 | Raspberry Pi Pico **H** (or Pico + pin headers) | 1 | Official / clone with headers | Plugs into female 1×20×2 |
| 2 | Female header 2.54 mm 1×20 | 2 | Generic | Pico socket |
| 3 | 16×2 LCD **green backlight** HD44780 | 1 | Module with pin row | Female 1×16 header |
| 4 | Female header 1×16 2.54 mm | 1 | Generic | LCD socket |
| 5 | **4-ch bidirectional level converter** BSS138 / I²C IIC | **5** | Hobby module ~15×13 mm, pin headers | **OK / preferred** — LCD1602 **5 V I²C backpack** ↔ Pico **3.3 V**; **LV=3.3 V** · **HV=5 V** · **GND** common — **not** for TFT |
| 6 | 16-pin DIP socket 0.3″ | 1 | Generic / turned-pin if budget allows | Modem IC |
| 7 | TCM3105 DIP **or** MX614P-class | 1 | Verify stock / NOS carefully | Insert in socket only |
| 8 | Crystal 4.433619 MHz HC-49 | 1 | Commodity | Confirm vs modem datasheet |
| 9 | Buck module 12→5 V ≥0.5 A | 1 | MP1584 / LM2596 module | Header pins |
| 10 | USB Type-A receptacle TH | 1 | Commodity | — |
| 11 | Barrel jack 5.5×2.1 centre+ | 1 | Commodity | — |
| 12 | Screw terminal 4-pin 5.08 mm | 1 | Commodity | AF/PTT labels |
| 13 | 1N5819 Schottky | 2 | TH | OR diodes |
| 14 | 1N4148 | 2 | TH | Clamp |
| 15 | 2N2222A or BC547 | 1 | TO-92 | PTT |
| 16 | Resistors 0.25 W (330R, 1k, 4.7k, 10k, …) | pack | Assortment OK | TH |
| 17 | Caps 100 nF + 100 µF electrolytic | pack | Commodity | TH / radial |
| 18 | Trimmer 10 kΩ TH | 2–3 | Carbon / cermet | Contrast + TX level |
| 19 | LED 3 mm + tactile switch | 4+1 | Commodity | — |
| 20 | 12 V wall wart 5.5×2.1 ≥0.5 A | 1 | Commodity centre+ | Off-board |
| 21 | USB-A cable (PC → T-Modem) | 1 | Commodity | Device port |

Exact DigiKey/Reichelt order codes = **TBD at cart time** (stock moves). Prefer parts that stay in catalogues for years.

---

## Cost realism (order of magnitude, not a quote)

Excluding PCB fab and NOS modem premium: a careful hobby cart for sockets + Pico + LCD + buck + connectors + passives is typically in the **low tens of €** region at EU hobby shops; TCM3105/MX614 availability can dominate cost if only broker stock exists. Soft-AFSK-only (no modem IC) is a later cost escape hatch (firmware) — not the v0.25 preferred PHY.

---

## Sources

| Claim | Rights-granting source | Local copy |
|---|---|---|
| Pico / RP2040 | https://datasheets.raspberrypi.com/pico/pico-datasheet.pdf | — |
| TCM3105 mirror | https://www.qsl.net/o/on7pc/datasheet/ic/TCM3105.pdf | — |
| GPLv3 | https://www.gnu.org/licenses/gpl-3.0.html | `../LICENSE` |

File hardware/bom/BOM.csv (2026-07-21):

Ref | Qty | Description | Preferred_candidate | Notes | Status
SKT_MODEM | 1 | 16-pin DIP socket 0.3 inch | TE/Mill-Max/generic turned-pin | Hobby: do not solder modem IC directly | Preferred
HDR_PICO_F | 2 | Female header 1x20 2.54mm | Commodity | Socket for Pico H | Preferred
HDR_LCD_F | 1 | Female header for 16x2 LCD 2.54mm | Commodity | Socket/header LCD | Preferred
HDR_REG | 1 | Header for buck module 2.54mm | Commodity | Plug-in 12V-to-5V module | Candidate
U1 | 1 | MCU module native USB UF2 | Raspberry Pi Pico H (headers) | Field flash UF2 via USB Type-A path | Preferred
U_MODEM | 1 | Bell-202 AFSK modem IC DIP-16 | TCM3105 DIP-16 or MX614P-class | Insert in SKT_MODEM; NOT BayCom/SER12; check NOS stock | Preferred_class
U_MODEM_ALT | 0 | Alt Bell-202 modem | MX614-class if TCM3105 unavailable | Same net role as U_MODEM | Optional
Y1 | 1 | Crystal for TCM3105 | 4.433619 MHz HC-49 TH | Load caps per datasheet | Candidate
U_REG | 1 | 12V to 5V regulator module | MP1584EN buck module on headers | Prefer module over soldering SOIC buck | Candidate
D_OR1 | 1 | Schottky OR diode TH | 1N5819 | PSU to +5V_OR | Candidate
D_OR2 | 1 | Schottky OR diode TH | 1N5819 | VBUS to +5V_OR no backfeed | Candidate
F1 | 1 | PTC ~0.5A hold TH or radial | DigiKey PTC 500mA class | On +5V | Candidate
C_IN | 1 | 100uF 25V electrolytic radial | Commodity | VIN_12 bulk | Candidate
C_BULK | 1 | 100uF 16V electrolytic radial | Commodity | +5V_OR bulk | Candidate
C_BYP | 8 | 100nF 50V ceramic TH or MLCC leaded | Prefer TH for hobby | Decoupling | Candidate
J_USB | 1 | USB Type-A receptacle TH USB2 FS | Amphenol/TE/Molex Type-A TH | Operator lock MPN TBD at order | Preferred_class
J_DC | 1 | Barrel 5.5x2.1 centre-positive TH | CUI PJ-002A class | Silk 12V CENTRE + | Preferred_class
J_AF | 1 | Screw terminal 4-pin 5.08mm TH | Phoenix/Wurth/generic | Silk AF_TX AF_RX PTT GND only | Candidate
DSP1 | 1 | 16x2 HD44780 LCD green backlight | Named OEM DigiKey/Mouser 16x2 green | Pin row into HDR_LCD_F | Preferred_class
U2 | 0 | Optional PCF8574 I2C backpack | Common backpack often 5V | Frees GPIO | Optional
U_LVL | 0 | 4-ch bidirectional BSS138 I2C level shifter | Hobby module ~15x13mm pin headers | LV=3.3V Pico HV=5V LCD I2C GND common; not TFT; required if 5V backpack | Preferred_I2C
RV1 | 1 | 10k trimmer TH | Bourns 3296 or carbon TH | TX AF | Candidate
RV2 | 1 | 10k trimmer TH | Same class as RV1 | LCD V0 | Candidate
RV_CDL | 1 | Trimmer TH CD level | Per TCM3105 datasheet | Carrier detect | Candidate
Q1 | 1 | NPN OC PTT TO-92 | 2N2222A or BC547 | Open collector | Candidate
R_PTT | 1 | 4.7k resistor 0.25W TH | Commodity | Q1 base | Candidate
R_LED | 4 | 330R-1k resistor 0.25W TH | Commodity | LED series | Candidate
R_BL | 1 | Backlight series R 0.25W TH | Per LCD module | Green BL | Candidate
R_PAD | 4 | 100R-10k resistors 0.25W TH | Commodity | AF pad/bias | Candidate
C_AC | 2 | 100nF film or ceramic TH | Commodity | AF AC couple | Candidate
D_PROT | 2 | 1N4148 TH | Commodity | AF clamp | Candidate
LED1 | 1 | 3mm LED green TH | Commodity | PWR | Candidate
LED2 | 1 | 3mm LED TH | Commodity | PTT | Candidate
LED3 | 1 | 3mm LED TH | Commodity | DCD | Candidate
LED4 | 1 | 3mm LED TH | Commodity | TX/RX | Candidate
SW1 | 1 | Tactile N.O. 6x6 TH | Omron B3F / TE class | BOOTSEL to GND | Candidate
PSU_WALL | 1 | 12V centre-positive wall wart 5.5x2.1 >=0.5A | Commodity | Not on PCB | Candidate

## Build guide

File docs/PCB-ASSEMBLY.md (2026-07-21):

# PCB outline and assembly — v0.25

**Status:** complete hand-solderable **reference PCB** (TH + sockets)  
**Board size:** **190 × 110 mm** · 2-layer FR4 · 1.6 mm  
**AS-IS:** no support, no warranty · first fab = operator responsibility

Companion: [SCHEMATIC.md](SCHEMATIC.md) · [BOM.md](BOM.md) · [PCB-LAYOUT.md](PCB-LAYOUT.md) · KiCad [`../hardware/kicad/t-modem/`](../hardware/kicad/t-modem/) · mechanical [`../hardware/mechanical/outline-190x110.md`](../hardware/mechanical/outline-190x110.md) · fab [`../hardware/fab/README.md`](../hardware/fab/README.md)

---

## Outline

| Item | Value |
|---|---|
| Outer | Rectangle **190.0 × 110.0 mm** (X × Y) |
| Origin | Lower-left corner of board |
| Mounting | M3 holes ≈ inset **6 mm** → (6,6), (184,6), (6,104), (184,104) |
| Keep-out | 2 mm from edge for overhanging connectors |

Larger than the early 100×80 draft per safe · stable · performant layout (§0.26).

---

## Placement (top view, silk facing up)

| Ref | Region | Notes |
|-----|---|---|
| J_USB | Front / left | Type-A receptacle — **USB DEVICE** |
| J_USB_PICO | Near J_USB | 1×4 — silk **to Pico Micro-USB cable** (Path B) |
| J_DC | Front | Barrel — **12 V CENTRE +** |
| SW1 + TP_BOOTSEL | Front | BOOTSEL tactile + wire pad to Pico BOOTSEL TP |
| U_REG / F1 / D_OR* / C_* | Front-right | Power island + Schottky OR |
| U1 Pico | Centre | `RaspberryPi_Pico_Common_THT` female headers; Pico H plugs in |
| SKT_MODEM | Left | DIP-16 socket for TCM3105 (`U_MODEM`) |
| Y1 + C_Y* | Near modem | 4.433619 HC-49-U Vertical + load caps |
| R_TRS / R_TXR1 / R_TXR2 | Left of modem | 0 Ω straps — silk **confirm datasheet** |
| J_AF | Right | Phoenix MSTBA 1×4 5.08 — **AF_TX AF_RX PTT GND** |
| Q1 + R_PTT | Mid-right | 2N2222A TO-92 + 4.7 kΩ |
| LED* + R_LED* | Right | 3 mm ×4 |
| U_LVL | Top | BSS138 module headers — LV=`3V3`, HV=`+5V_OR` |
| J_LCD_I2C | Top | 1×4 **GND VCC SDA SCL** (default I²C LCD) |
| RV1 / RV_CDL / RV2 | Upper mid | Bourns 3296W — TX level, CDL, contrast (RV2 optional if backpack has own) |

```text
Y=110 ┌──────────────────────────────────────────────────────────────┐
      │  U_LVL          J_LCD_I2C (I2C)                               │
      │  SKT_MODEM          U1 Pico H                  J_AF          │
      │  TCM3105            (USB end→front)            screw         │
      │                                                               │
Y=0   │  J_USB  J_USB_PICO  J_DC  SW1   power / LEDs                 │
      └──────────────────────────────────────────────────────────────┘
       X=0                                                        X=190
```

---

## USB Path B (settled)

Type-A receptacle on board. **VBUS** → Schottky OR into `+5V_OR`. **D+/D−/GND** (+ VBUS) also to `J_USB_PICO` for a short cable into the Pico Micro-USB. Silk: **to Pico Micro-USB cable**.

---

## LCD default — I²C

`J_LCD_I2C` via `U_LVL` (BSS138-class). Pico **GP0/GP1** = SDA/SCL (3.3 V side).

---

## Hobby-friendly soldering

| Rule | Detail |
|---|---|
| **Sockets** | SKT_MODEM DIP-16 before IC; female 2.54 mm for Pico |
| **Through-hole** | Prefer TH resistors, diodes, LEDs, trimmers, USB-A / barrel / screw |
| **Modules** | Pico H; MP1584-class buck on 1×3 header |

---

## Assembly order

1. Passives and diodes (D_OR*, R*, C*) — TH  
2. F1, crystal + load caps, U_REG headers  
3. **SKT_MODEM** — do not solder the IC directly  
4. Female headers for Pico  
5. J_USB, J_USB_PICO, J_DC, J_AF, SW1, LEDs, trimmers, U_LVL, J_LCD_I2C  
6. Insert modem IC · Pico · LCD backpack cable  
7. 12 V alone → measure `+5V_OR` ≈ 5 V; then USB-only OR path  

**RX before TX** when RF attached later.

---

## Sources

| Claim | Rights-granting source | Local copy |
|---|---|---|
| Product / GPLv3 | https://github.com/ngteq/T-Modem · https://www.gnu.org/licenses/gpl-3.0.html | `../LICENSE` |
| Electrical nets | [SCHEMATIC.md](SCHEMATIC.md) | — |

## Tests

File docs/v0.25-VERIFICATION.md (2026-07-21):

# v0.25 verification report

**Date:** 2026-07-20 · **refresh:** 2026-07-21  
**Repo:** `ngteq/T-Modem`  
**Tag intent:** `v0.25`  
**Scope:** hardware-without-software standard reference (AS-IS · GPLv3)

Self-audit against milestone checklist. Verdicts: **PASS** / **FAIL** / **TBD**.

---

## Checklist

| # | Requirement | Verdict | Evidence / notes |
|---|---|---|---|
| 1 | Green LCD (preferred) or TFT alt documented | **PASS** | [BOM.md](BOM.md) DSP1 16×2 green HD44780 preferred; TFT as optional alt in [HARDWARE-INTENT.md](HARDWARE-INTENT.md) / Eckpunkte (vault) |
| 2 | USB Type A receptacle | **PASS** | J_USB in BOM + [SCHEMATIC.md](SCHEMATIC.md); silk USB DEVICE |
| 3 | Power path (USB and/or 12 V) designed | **PASS** | USB-only via `D_OR2`; optional `J_DC` + `U_REG` on reference — [SCHEMATIC.md](SCHEMATIC.md) Power rationale |
| 4 | MCU with USB field-flash (UF2/DFU) candidate | **PASS** | Raspberry Pi Pico / RP2040 UF2 + BOOTSEL in BOM |
| 5 | BOM with commodity candidates + longevity notes | **PASS** | [BOM.md](BOM.md) · [BOM.csv](../hardware/bom/BOM.csv); TCM3105 longevity **TBD**/NOS called out; connector MPNs **TBD** at order |
| 6 | Schematic: KiCad **or** fabricable netlist | **PASS** | Authoritative netlist [SCHEMATIC.md](SCHEMATIC.md); KiCad project present |
| 7 | PCB: outline, placement, assembly notes | **PASS** | **190 × 110 mm** — [PCB-ASSEMBLY.md](PCB-ASSEMBLY.md) · [outline-190x110.md](../hardware/mechanical/outline-190x110.md) · KiCad PCB |
| 8 | AFSK/modem analog path (TCM3105-class; **not** BayCom/SER12) | **PASS** | U_MODEM TCM3105 nets + AF IF + PTT OC in SCHEMATIC/BOM; SER12 forbidden |
| 9 | No firmware (placeholder only) | **PASS** | [../firmware/README.md](../firmware/README.md) · [../software/README.md](../software/README.md) |
| 10 | AS-IS, standard-reference-only, GPLv3 | **PASS** | Root README · LICENSE · CONTRIBUTING · release note |
| 11 | This self-audit report | **PASS** | This file |

---

## Honesty limits (not FAIL for HW-without-FW milestone)

| Topic | Status |
|---|---|
| Fully routed / fab-house-verified Gerbers | **Not claimed** — Gerbers generatable; clear DRC before order |
| Exact USB-A / LCD / barrel DigiKey MPN | **TBD** at order (connector **class** settled) |
| TCM3105 retail stock | **TBD** — legacy/NOS; MX614 alt documented |
| Pico USB Type-A vs module Micro-USB | Path B in SCHEMATIC |
| AFSK 2400 | FW DSP later — hardware reserves MCU; 1200 via TCM3105 |
| On-air / soldered prototype proof | **Out of scope** for docs milestone |

**Milestone claim:** v0.25 is a **meaningful hardware reference** (power · USB device · green LCD · UF2 MCU · TCM3105-class modem IF · PCB · BOM) so that **once firmware exists**, the electrical design is specified enough to assemble and bring up. It is **not** a claim that boards are already fabbed or that firmware works.

---

## Sources

| Claim | Rights-granting source | Local copy |
|---|---|---|
| GPLv3 | https://www.gnu.org/licenses/gpl-3.0.html | `../LICENSE` |
| Product repo | https://github.com/ngteq/T-Modem | — |

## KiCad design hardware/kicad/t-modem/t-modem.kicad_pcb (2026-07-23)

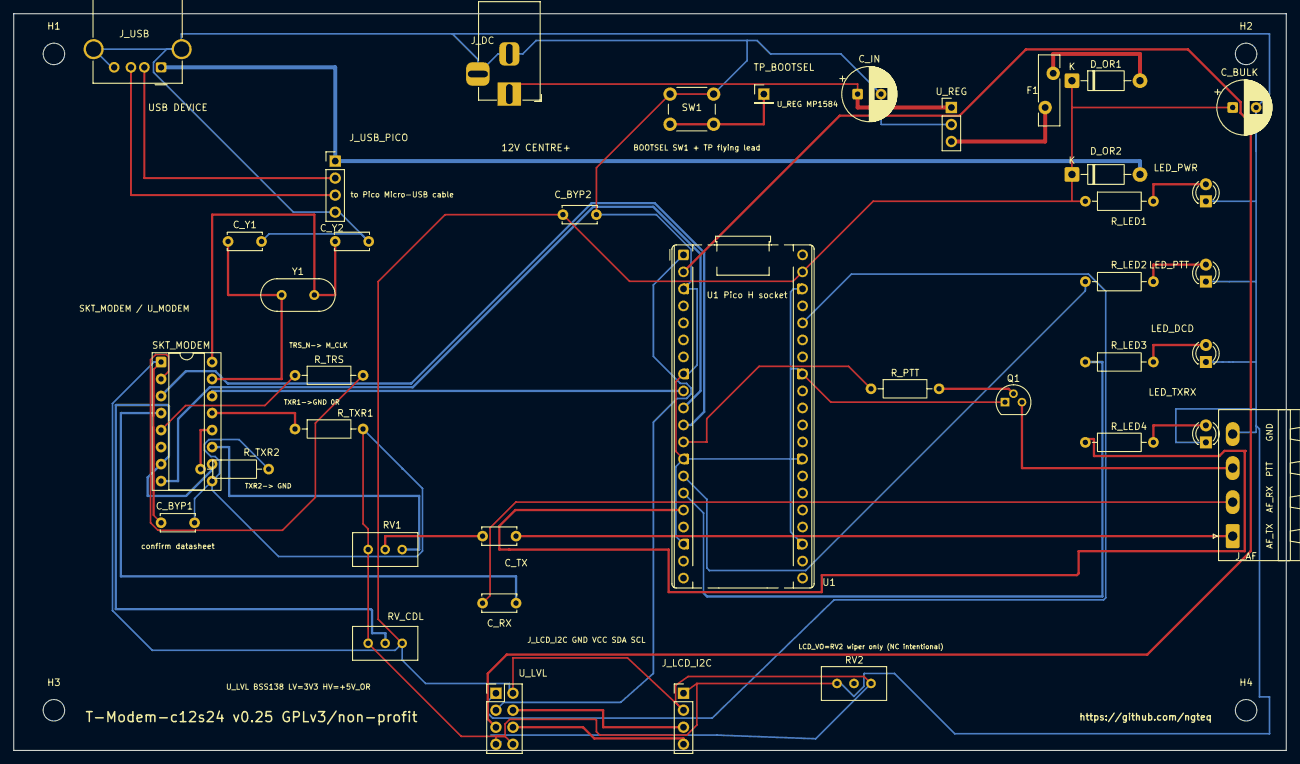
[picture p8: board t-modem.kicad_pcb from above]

Board: 2 copper layers, 190.0 x 110.0 mm, 43 parts (0 on the bottom side), 39 nets.

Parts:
C_BULK: 100uF; CP_Radial_D8.0mm_P3.50mm
C_BYP1, C_BYP2: 100nF; C_Disc_D5.0mm_W2.5mm_P5.00mm
C_IN: 100uF; CP_Radial_D8.0mm_P3.50mm
C_RX: 100nF; C_Disc_D5.0mm_W2.5mm_P5.00mm
C_TX: 100nF; C_Disc_D5.0mm_W2.5mm_P5.00mm
C_Y1, C_Y2: 22pF; C_Disc_D5.0mm_W2.5mm_P5.00mm
D_OR1, D_OR2: 1N5819; D_DO-41_SOD81_P10.16mm_Horizontal
F1: MF-RG500; Fuse_Bourns_MF-RG500
H1, H2, H3, H4: M3; MountingHole_3.2mm_M3
J_AF: AF; PhoenixContact_MSTBA_2,5_4-G-5,08_1x04_P5.08mm_Horizontal
J_DC: 12V CENTRE+; BarrelJack_Horizontal
J_LCD_I2C: LCD I2C; PinHeader_1x04_P2.54mm_Vertical
J_USB: USB_A; USB_A_Molex_67643_Horizontal
J_USB_PICO: to Pico Micro-USB cable; PinHeader_1x04_P2.54mm_Vertical
LED_DCD: DCD; LED_D3.0mm
LED_PTT: PTT; LED_D3.0mm
LED_PWR: PWR; LED_D3.0mm
LED_TXRX: TXRX; LED_D3.0mm
Q1: 2N2222A; TO-92
RV1: 10k TX; Potentiometer_Bourns_3296W_Vertical
RV2: 10k contrast; Potentiometer_Bourns_3296W_Vertical
RV_CDL: 50k CDL; Potentiometer_Bourns_3296W_Vertical
R_LED1, R_LED2, R_LED3, R_LED4: 1k; R_Axial_DIN0207_L6.3mm_D2.5mm_P10.16mm_Horizontal
R_PTT: 4.7k; R_Axial_DIN0207_L6.3mm_D2.5mm_P10.16mm_Horizontal
R_TRS: 0R; R_Axial_DIN0207_L6.3mm_D2.5mm_P10.16mm_Horizontal
R_TXR1, R_TXR2: 0R; R_Axial_DIN0207_L6.3mm_D2.5mm_P10.16mm_Horizontal
SKT_MODEM: U_MODEM TCM3105; DIP-16_W7.62mm_Socket
SW1: BOOTSEL; SW_PUSH_6mm
TP_BOOTSEL: to Pico BOOTSEL; PinHeader_1x01_P2.54mm_Vertical
U1: RaspberryPi_Pico; RaspberryPi_Pico_Common_THT
U_LVL: BSS138; PinHeader_2x04_P2.54mm_Vertical
U_REG: MP1584 VIN GND 5V; PinHeader_1x03_P2.54mm_Vertical
Y1: 4.433619; Crystal_HC49-U_Vertical

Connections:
3V3: U1.36, U_LVL.1
+5V: D_OR1.2, F1.2
+5V_OR: C_BULK.1, C_BYP1.1, C_BYP2.1, D_OR1.1, D_OR2.1, J_LCD_I2C.2, RV2.1, RV_CDL.1, R_LED1.1, SKT_MODEM.1, U1.39, U_LVL.2
+5V_REG: F1.1, U_REG.3
AF_RX: C_RX.1, J_AF.2
AF_TX: C_TX.2, J_AF.1
BOOTSEL: SW1.2, TP_BOOTSEL.1
CDL: RV_CDL.2, SKT_MODEM.7, SKT_MODEM.10
GND: C_BULK.2, C_BYP1.2, C_BYP2.2, C_IN.2, C_Y1.2, C_Y2.2, J_AF.4, J_DC.2, J_DC.3, J_LCD_I2C.1, J_USB.4, J_USB.SH, J_USB_PICO.4, LED_DCD.1, LED_PTT.1, LED_PWR.1, LED_TXRX.1, Q1.1, RV1.3, RV2.3, RV_CDL.3, R_TXR1.2, R_TXR2.2, SKT_MODEM.9, SW1.1, U1.3, U1.8, U1.13, U1.18, U1.23, U1.28, U1.33, U1.38, U_LVL.7, U_LVL.8, U_REG.2
I2C_SCL_3V3: U1.2, U_LVL.5
I2C_SCL_5V: J_LCD_I2C.4, U_LVL.6
I2C_SDA_3V3: U1.1, U_LVL.3
I2C_SDA_5V: J_LCD_I2C.3, U_LVL.4
LED_DCD_A: LED_DCD.2, R_LED3.2
LED_DCD_N: R_LED3.1, U1.15
LED_PTT_A: LED_PTT.2, R_LED2.2
LED_PTT_N: R_LED2.1, U1.14
LED_PWR_A: LED_PWR.2, R_LED1.2
LED_TXRX_A: LED_TXRX.2, R_LED4.2
LED_TXRX_N: R_LED4.1, U1.16
MODEM_CDT: SKT_MODEM.3, U1.11
MODEM_CLK: R_TRS.2, SKT_MODEM.2
MODEM_RXD: SKT_MODEM.8, U1.10
MODEM_TXD: SKT_MODEM.14, U1.9
OSC1: C_Y1.1, SKT_MODEM.15, Y1.1
OSC2: C_Y2.1, SKT_MODEM.16, Y1.2
PTT_B: Q1.2, R_PTT.2
PTT_DRV: R_PTT.1, U1.12
PTT_OC: J_AF.3, Q1.3
RXA: C_RX.2, SKT_MODEM.4
TRS_N: R_TRS.1, SKT_MODEM.5
TXA: RV1.1, SKT_MODEM.11
TXR1_N: R_TXR1.1, SKT_MODEM.13
TXR2_N: R_TXR2.1, SKT_MODEM.12
TX_LVL: C_TX.1, RV1.2
USB_DM: J_USB.2, J_USB_PICO.2
USB_DP: J_USB.3, J_USB_PICO.3
VBUS: D_OR2.2, J_USB.1, J_USB_PICO.1
VIN_12: C_IN.1, J_DC.1, U_REG.1

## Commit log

2026-07-21 T-Modem-c12s24: hardware reference baseline.
    Chip 1200 + software 2400 path; v0.25 docs and KiCad tree.
    [BOM.csv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]
2026-07-22 v0.25-pcb-ready-for-prototype
    Promote routed copper board to t-modem.kicad_pcb (DRC short/unconn/cross 0/0/0); drop workcopies and Freerouting artifacts from the tree.
    [t-modem.kicad_pcb]
2026-07-22 docs(kicad): drop generate_board reference after script removal
2026-07-22 fix(pcb): restore copper clearances before fab etch risk
    LED_TXRX_N↔AF_TX and CDL↔TXR2_N were under 0.2 mm; nudge stubs so DRC clearance is clean while keeping short/unconn/cross at 0.
    [t-modem.kicad_pcb]
2026-07-23 fix(pcb): pull U_LVL and J_LCD_I2C on-board at bottom edge
    Bottom-row pads/vias sat on Edge.Cuts (y≈109.62); move footprints
    inward 0.55 mm so copper is fully on-board without breaking routing.
    [t-modem.kicad_pcb]
2026-07-23 fix(pcb): polish edge placement for prototype-ready layout
    Nudge silkscreen/refdes and connector positions off the board edge so the
    c12s24 PCB reads as fabrication-ready without further edge cleanup.
    [t-modem.kicad_pcb]
2026-07-23 fix(pcb): reposition board silkscreen title for prototype layout
    Further PCB polish toward prototype: move F.SilkS title text onto a clearer board area.
    [t-modem.kicad_pcb]
2026-07-23 Refresh 1:1 board image and explode teaching set for builders.
    Regenerate complete + 10 KiCad-based explode panels from gold PCB so assembly/subsystem layout is clear without inventing 3D CAD.
2026-07-23 Remove superseded sketch explode PNGs.
    Replace the old five German sketch panels with the KiCad teaching set already pushed.
2026-07-23 Restore assembled complete.png with Pico via KiCad 3D render.
    Replace the bare copper/silk SVG companion with a raytraced top view of the gold PCB (Pico H seated, front edge at bottom). Keep the 2D explode teaching set unchanged unless --explode/--all is used.
2026-07-24 Rotate complete.png board 180° for upright silkscreen reading.
    Camera yaw was 180° which put silk upside-down relative to title/footer; set render rotate to 0,0,0 and flip the composed board region so regenerates stay readable.

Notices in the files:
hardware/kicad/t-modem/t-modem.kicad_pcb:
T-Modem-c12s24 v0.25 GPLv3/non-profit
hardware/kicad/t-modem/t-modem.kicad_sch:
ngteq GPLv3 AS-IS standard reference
